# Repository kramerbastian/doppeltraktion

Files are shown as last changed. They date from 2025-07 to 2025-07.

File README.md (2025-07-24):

# *doppeltraktion*

Doppeltraktion (German for double heading — that's when two locomotives pull together on a train) is the world's most intuitive model railway throttle. It has ≈6x fewer buttons and switches than market competitors, such as the Uhlenbrock Intellibox II. It connects to your model railroad using LCC or to your computer via USB to control software such as RocRail or JMRI*¹ and can control two locomotives simultaneously. <br>
<sub>*¹ not yet implemented</sub>

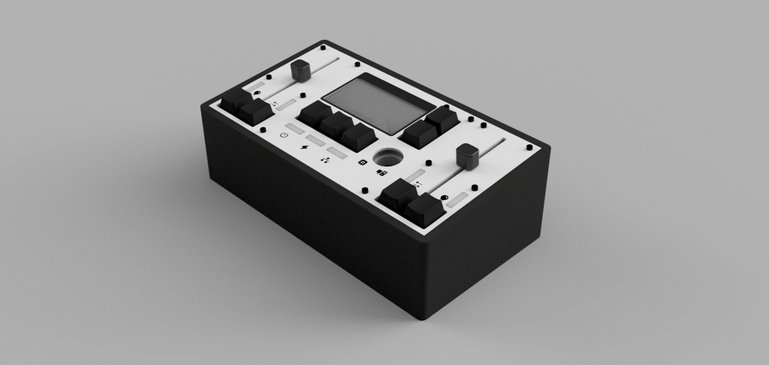
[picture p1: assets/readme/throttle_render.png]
Rendered model


### Functions

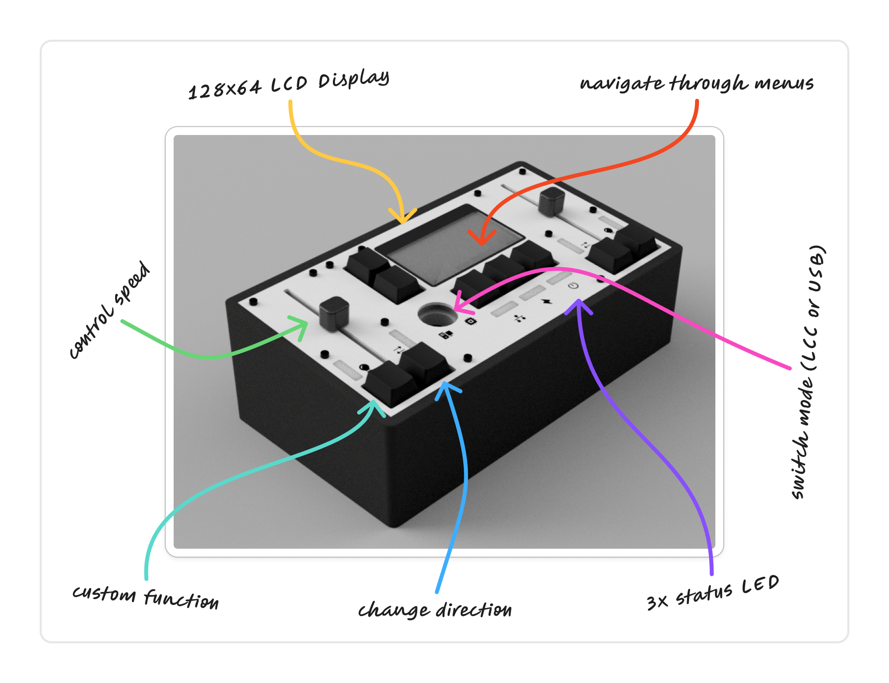
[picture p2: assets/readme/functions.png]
Functions of the throttle


### What is LCC?

LCC is a relatively new standard by the NMRA to control devices using a CAN bus. It's completely free and open-source, unlike alternatives like LocoNet, which comes with a pretty hefty licensing fee for device manufacturers.

### Motivation

I've been building on my model railway from an early age. As time progressed, the electronics and operations became so complicated that nobody else could really control it. That's why I always wanted to build a physical throttle that's not dependent on external computers or phones. Everything should be ready to use when you turn on the power. Of course, there are alternatives from big manufacturers, such as the mentioned Intellibox or the ESU ECoS, but these devices are very expensive (500€+) and aren't compatible with my DIY DCCEX base station.

### Design

It might seem a bit unusual to have five PCBs for this relatively small project, but to keep PCB costs low (by being under 100x100mm), I decided to split the covers (aluminum PCBs) and those boards where the switches, LEDs, and potentiometers mount. The PCBs on the side are identical. Everything is connected to a custom, small control board, which houses the ESP32 as well as all the CAN circuitry (for LCC).
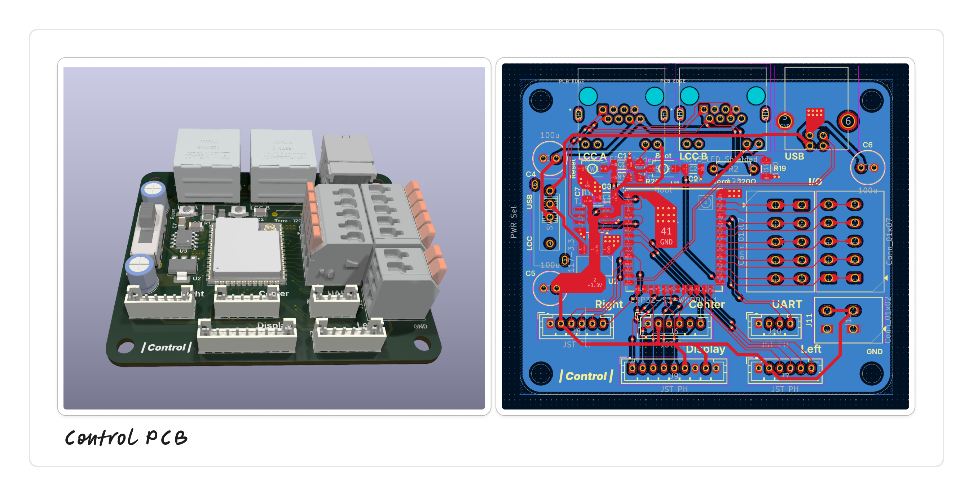
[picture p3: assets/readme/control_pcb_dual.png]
control PCB

By also splitting the base into two parts, everything should fit on the 180x180mm build plate of the A1 mini.

The plates (that‘s where the switches mount mechanically) use a sandwich design (top plate - bottom plate - PCB) to avoid having to use supports and ensure dimensional accuracy for mounting the switches.

I couldn’t find a good CAD model or accurate dimensions for the 16mm selector knob, so there’s a hole in the cover and the plates beneath it. The cutout size should be correct. I just need to verify the depth and maybe adjust the top side plate once the switch arrives.

#### Designed Parts

| Name | Image | File | Quantity  |
|---|---|---|---|
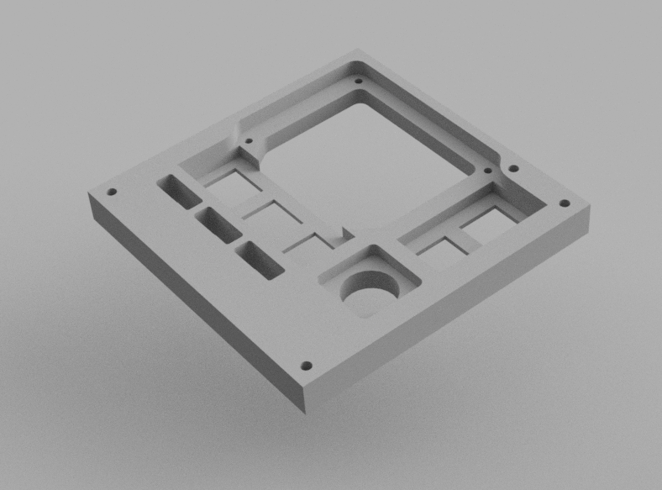
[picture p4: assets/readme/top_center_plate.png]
top center plate
| Top center plate |  | [STL](./production/3d/top_center_plate.stl) | 1 |
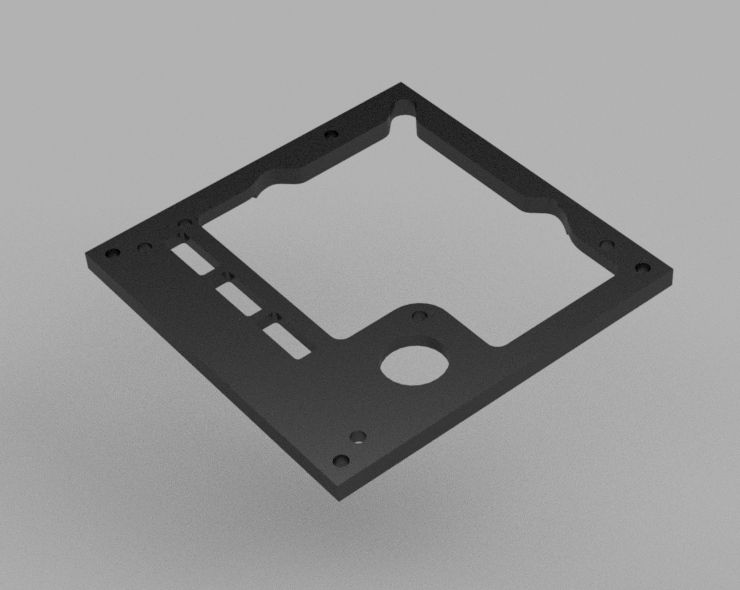
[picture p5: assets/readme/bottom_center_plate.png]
bottom center plate
| Bottom center plate |  | [STL](./production/3d/bottom_center_plate.stl) | 1 |
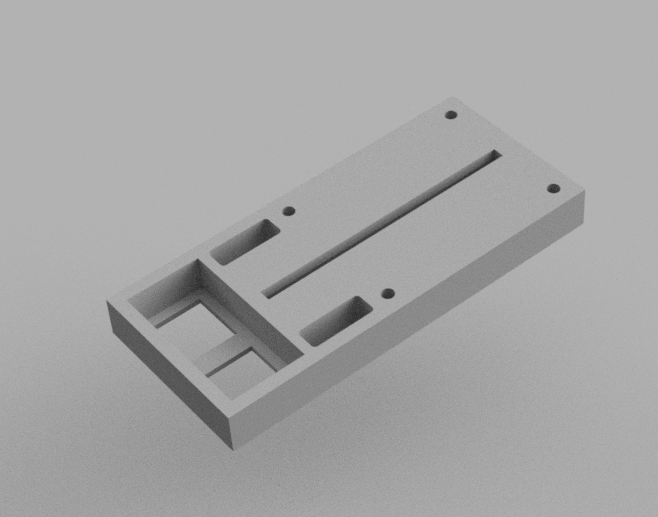
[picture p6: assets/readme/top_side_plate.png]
top side plate
| Top side plate |  | [STL](./production/3d/top_side_plate.stl) | 2 |
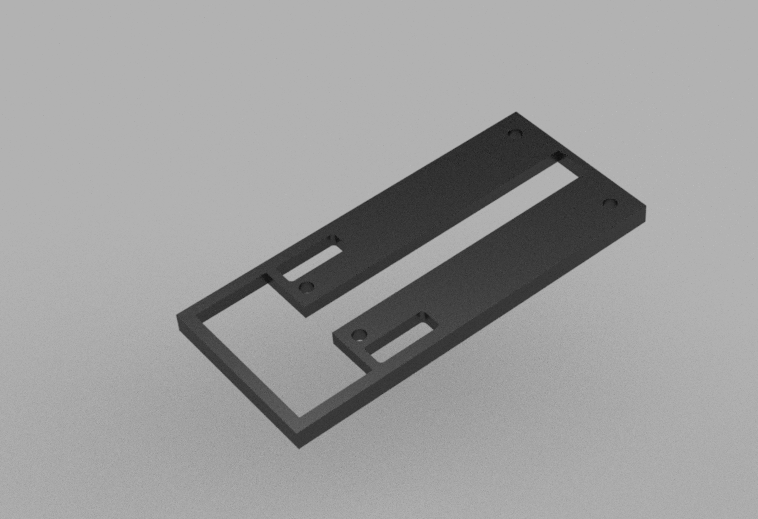
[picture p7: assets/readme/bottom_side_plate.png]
bottom side plate
| Bottom side plate |  | [STL](./production/3d/bottom_side_plate.stl) | 2 |
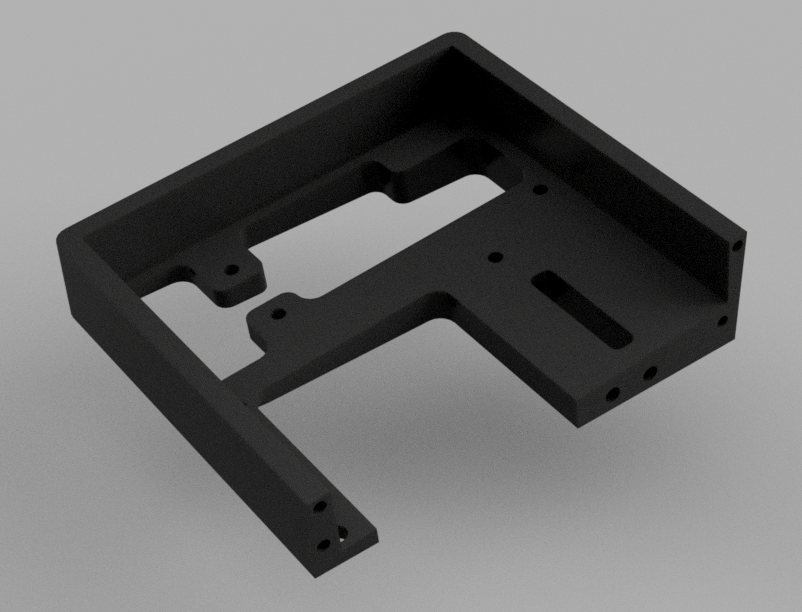
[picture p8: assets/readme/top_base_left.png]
top left base
| Top left base |  | [STL](./production/3d/top_base_left.stl.stl) | 1 |
| Top right base | bottom left base | [STL](./production/3d/top_base_right.stl) | 1 |
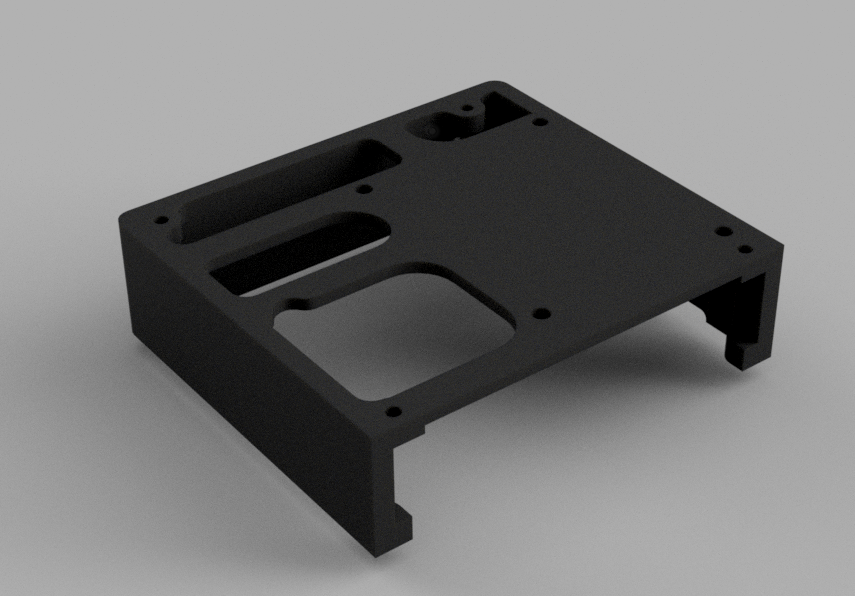
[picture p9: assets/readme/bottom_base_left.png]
bottom left base
| Bottom left base |  | [STL](./production/3d/bottom_base_left.stl.stl) | 1 |
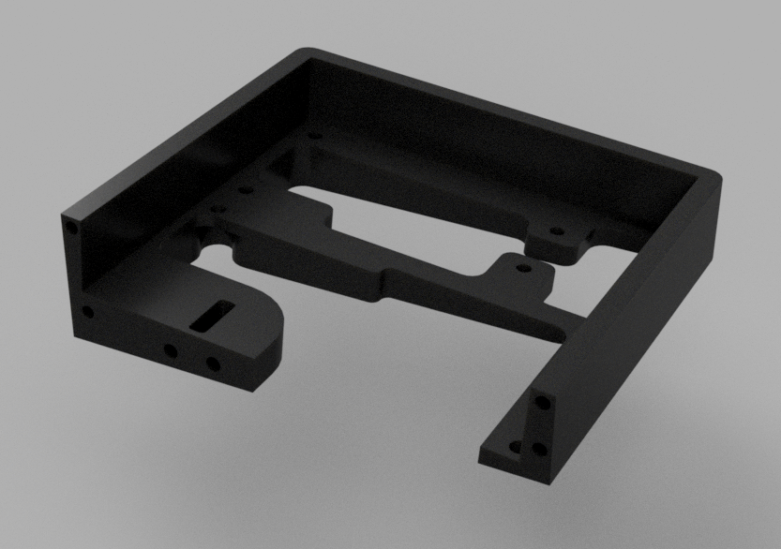
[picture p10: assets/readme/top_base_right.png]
bottom right base
| Bottom right base |  | [STL](./production/3d/bottom_base_right.stl) | 1 |
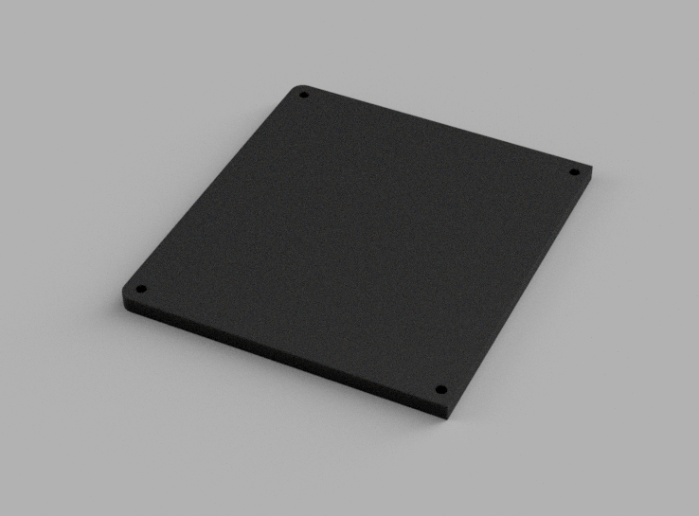
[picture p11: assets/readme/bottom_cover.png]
bottom left cover
| Bottom cover |  | [STL](./production/3d/bottom_cover.stl) | 2 |
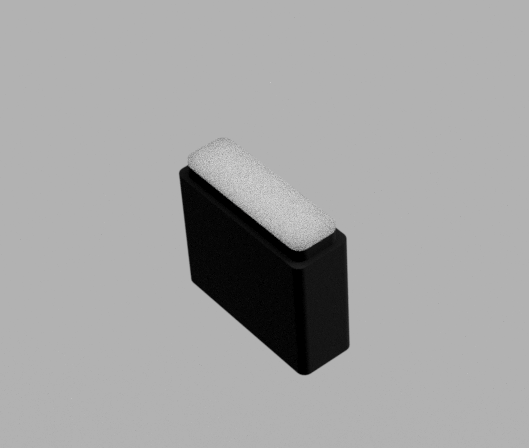
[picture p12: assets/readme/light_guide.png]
| Light guide <br> (print the last layer in white PLA)  |  | [STL](./production/3d/light_guide.stl) | 7 |
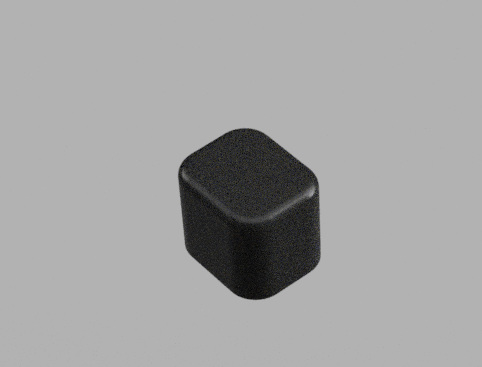
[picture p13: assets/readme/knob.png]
| Knob |  | [STL](./production/3d/knob.stl) | 1 |
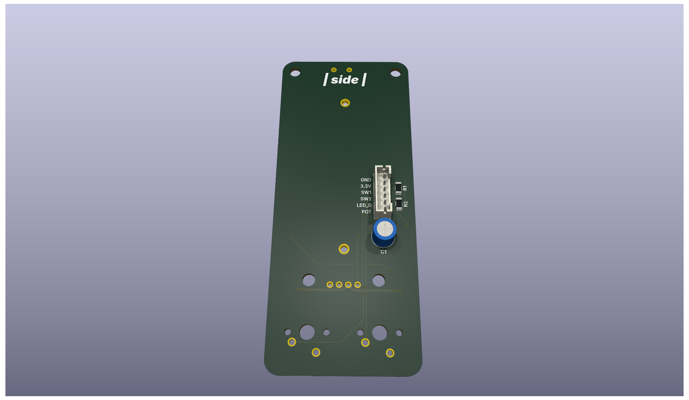
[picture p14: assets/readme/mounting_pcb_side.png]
| Mounting PCB side |  | [Gerber](./production/pcbs/side.zip) | 2 |
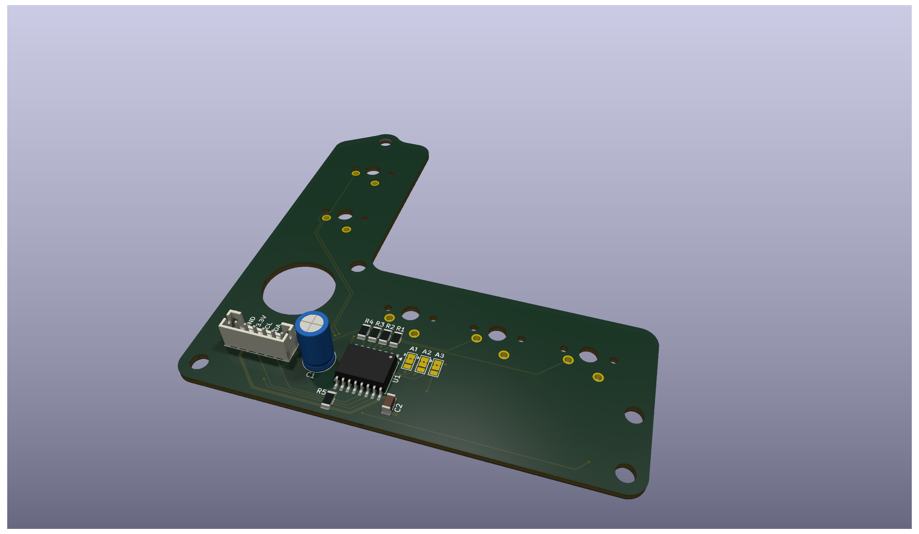
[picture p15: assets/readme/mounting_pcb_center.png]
| Mounting PCB center |  | [Gerber](./production/pcbs/center.zip) | 1 |
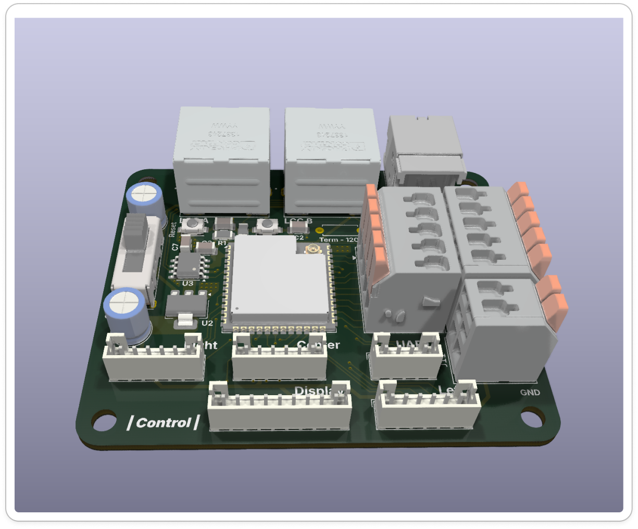
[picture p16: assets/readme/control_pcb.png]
| Control PCB |  | [Gerber](./production/pcbs/control.zip) | 1 |
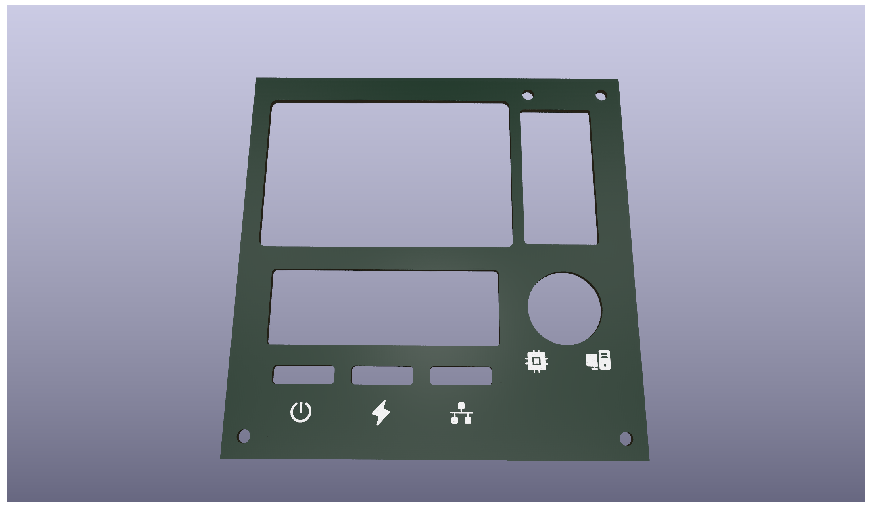
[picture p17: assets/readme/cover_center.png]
| Center cover |  | [Gerber](./production/pcbs/cover_center.zip) | 1 |
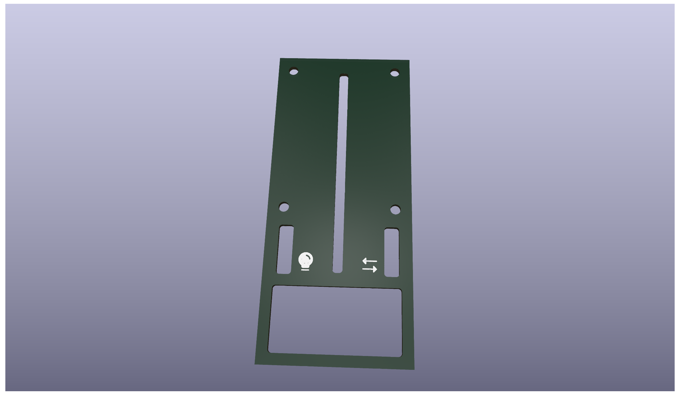
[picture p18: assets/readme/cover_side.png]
| Side cover |  | [Gerber](./production/pcbs/cover_side.zip) | 2 |

### Assembly

1. Print all necessary parts: 2x [top side plate](./production/3d/top_side_plate.stl), 2x [bottom side plate](./production/3d/bottom_side_plate.stl), 1x [top center plate](./production/3d/top_center_plate.stl), 1x [bottom center plate](./production/3d/bottom_center_plate.stl), 1x [top left base](./production/3d/top_base_left.stl), 1x [top right base](./production/3d/top_base_right.stl), 1x [bottom left base](./production/3d/bottom_base_left.stl), 1x [bottom right base](./production/3d/bottom_base_right.stl), 1x [bottom left cover](./production/3d/bottom_cover_left.stl), 1x [bottom right cover](./production/3d/bottom_cover_right.stl). (I know these names are awful, but I couldn‘t come up with better ones.)

2. Insert the heat-set inserts into their respective holes.

3. Mount all the PCBs and solder the switches in place.

4. You can now secure the plates onto the top base. With the control board mounted on the bottom base, it can also be secured to the top base.

5. Now is the time to run the wires from the modules (2x side, 1x center) and the display to the control board. Also, wire up the selector knob to the WAGO terminals and ground.

6. The final step is to screw both the top cover (the aluminium one) and the bottom cover onto the construction.

### BOM

|Part |Manufacturer |Product |Quantity|Price each|Total Price|Link |
|---|---|---|---|---|---|---|
|Inserts |YMAX |Brass Threaded Insert Nut Kit |1 | $1.460 | $1.46 | [Link](https://www.aliexpress.com/item/1005006472962973.html) |
|Display |EstarDyn |12864-06D |1 | $6.250 | $6.25 |[Link](https://www.aliexpress.com/item/1005006160620381.html) |
|Rotary Knob |Sweideer |LA-155C |1 | $2.630 | $2.63 |[Link](https://www.aliexpress.com/item/1005007495183351.html) |
|Switches |- |10 Pieces Keyboard Replacement Parts|1 | $1.590 | $1.59 |[Link](https://www.aliexpress.com/item/1005004341695529.html) |
|Keycaps |- |B0KA 20PCs PBT Blank |1 | $4.470 | $4.47 |[Link](https://www.aliexpress.com/item/1005004525231272.html) |
|M2x5 12x |SCREWHOME |50pcs M2x5mm ULTRATHIN |1 | $1.460 | $1.46 |[Link](https://www.aliexpress.com/item/1005005070119421.html) |
|M2x10 4x |LIYA |50pcs M2x10mm |1 | $1.560 | $1.56 |[Link](https://www.aliexpress.com/item/32810872544.html) |
|M3x20 2x |LIYA |50pcs M3x20mm |1 | $2.760 | $2.76 |[Link](https://www.aliexpress.com/item/32810872544.html) |
|M3x8 8x |LIYA |50pcs M3x8mm |1 | $1.730 | $1.73 |[Link](https://www.aliexpress.com/item/32810872544.html) |
|M3x8 Countersunk 8x |ZONST |50pcs M3x8mm Countersunk |1 | $1.810 | $1.81 |[Link](https://www.aliexpress.com/item/1005002333132596.html) |
|M3x12 12x |LIYA |50pcs M3x12mm |1 | $2.060 | $2.06 |[Link](https://www.aliexpress.com/item/32810872544.html) |
|M3x10 5x |LIYA |50pcs M3x10mm |1 | $1.940 | $1.94 |[Link](https://www.aliexpress.com/item/32810872544.html) |
|ESP32-S3 |EXPRESSIF |ESP32-S3-WROOM-1U-N16R2 |1 | $5.660 | $5.66 |[Link](https://lcsc.com/product-detail/WiFi-Modules_ESPRESSIF-ESP32-S3-WROOM-1U-N16R8_C3013946.html) |
|LDO |Advanced Monolithic Systems|AMS1117-3.3 |5 | $0.170 | $0.85 |[Link](https://lcsc.com/product-detail/Voltage-Regulators-Linear-Low-Drop-Out-LDO-Regulators_Advanced-Monolithic-Systems-AMS1117-3-3_C6186.html)|
|CAN transceiver |NXP |TJA1051T,118 |1 | $0.960 | $0.96 |[Link](https://lcsc.com/product-detail/CAN-Transceivers_NXP-TJA1051T-118_C18387.html) |
|I/O expander |HGSEMI |PCF8574T/TR |1 | $0.790 | $0.79 |[Link](https://lcsc.com/product-detail/I-O-Expanders_HGSEMI-PCF8574T-TR_C2987288.html) |
|4 pin connector |JST |B4B-PH-K-S(LF)(SN) |10 | $0.041 | $0.41 |[Link](https://lcsc.com/product-detail/Wire-To-Board-Connector_JST-B4B-PH-K-S-LF-SN_C131334.html) |
|6 pin connector |JST |B6B-PH-K-S(LF)(SN) |10 | $0.067 | $0.67 |[Link](https://lcsc.com/product-detail/Wire-To-Board-Connector_JST-B6B-PH-K-S-LF-SN_C131342.html) |
|9 pin connector |JST |B9B-PH-K-S(LF)(SN) |5 | $0.051 | $0.26 |[Link](https://lcsc.com/product-detail/Wire-To-Board-Connector_JST-B9B-PH-K-S-LF-SN_C157968.html) |
|4 pin connector housing  |JST |PHR-4 |50 | $0.016 | $0.79 |[Link](https://lcsc.com/product-detail/Housings-Wire-To-Board-Wire-To-Wire_JST-PHR-4_C111514.html) |
|6 pin connector housing  |JST |PHR-6 |20 | $0.020 | $0.40 |[Link](https://lcsc.com/product-detail/Housings-Wire-To-Board-Wire-To-Wire_JST-PHR-6_C157952.html) |
|9 pin connector housing  |JST |PHR-9 |20 | $0.036 | $0.72 |[Link](https://lcsc.com/product-detail/Housings-Wire-To-Board-Wire-To-Wire_JST-PHR-9_C157949.html) |
|Connector contact |JST |SPH-002T-P0.5S |100 | $0.008 | $0.80 |[Link](https://lcsc.com/product-detail/Housing-Contact_JST-SPH-002T-P0-5S_C111515.html) |
|USB-B port |TE Connectivity |292304-1 |1 | $0.470 | $0.47 |[Link](https://lcsc.com/product-detail/USB-Connectors_TE-Connectivity-292304-1_C86462.html) |
|100uF capacitors |Rubycon |35ZLH100MEFC6.3X11 |10 | $0.059 | $0.59 |[Link](https://lcsc.com/product-detail/Aluminum-Electrolytic-Capacitors-Leaded_Rubycon-35ZLH100MEFC6-3X11_C109392.html) |
|100nF capacitors |Samsung Electro-Mechanics  |CL31B104KBCNNNC |20 | $0.137 | $2.74 |[Link](https://lcsc.com/product-detail/Multilayer-Ceramic-Capacitors-MLCC-SMD-SMT_Samsung-Electro-Mechanics-CL31B104KBCNNNC_C24497.html) |
|10kOhm resistors |YAGEO |RC1206FR-0710KL |100 | $0.004 | $0.37 |[Link](https://lcsc.com/product-detail/Chip-Resistor-Surface-Mount_YAGEO-RC1206FR-0710KL_C132649.html) |
|Sliding potentiometers |ALPSALPINE |RS6011YA600M |2 | $1.451 | $2.90 |[Link](https://lcsc.com/product-detail/Potentiometers-Variable-Resistors_ALPSALPINE-RS6011YA600M_C470623.html) |
|RGB LEDs |XINGLIGHT |XL-5050RGBC-WS2812B |20 | $0.049 | $0.98 |[Link](https://lcsc.com/product-detail/RGB-LEDs-Built-in-IC_XINGLIGHT-XL-5050RGBC-WS2812B_C2843785.html) |
|RJ45 port - existing |Phoenix Contact |1337243 |2 | - | - |[Link](https://www.phoenixcontact.com/en-pc/products/rj45-pcb-connectors-cuc-sp-j1st-a-r4lt-thr-led-1337243) |
|WAGO terminals - existing|WAGO |2601-3105 |2 | - | - |[Link](https://www.wago.com/de/leiterplattenanschluss/leiterplattenklemme/p/2601-3105) |
|Slide switch - existing  |XKB Connection |SS13E05L2 |1 | - | - |[Link](https://lcsc.com/product-detail/Slide-Switches_XKB-Connection-SS13E05L2_C2884809.html) |
|Control PCB |JLCPCB |5x FR4 PCB |1 | $1.720 | $1.72 | |
|Side PCB |JLCPCB |5x FR4 PCB |1 | $3.440 | $3.44 | |
|Center PCB |JLCPCB |5x FR4 PCB |1 | $3.440 | $3.44 | |
|Center cover |JLCPCB |5x Aluminum PCB |1 | $3.390 | $3.39 | |
|Cover |JLCPCB |5x Aluminum PCB |1 | $3.390 | $3.39 | |
|JLCPCB shipping and taxes| | |1 | $11.020  | $11.02 | |
|LCSC shipping | | |1 | $9.420 | $9.42 | |
|**Total** | | | | | **$85.90**| |

#### Opening the CAD File
This project was built in multiple design files, which can‘t be combined without compromising the whole model. To import the CAD model, open Fusion 360, **create a new folder** and upload the [.f3z](./hardware/cad/Throttle.f3z) file into this created folder. You can now open the `Throttle` design file.

-------
<div style="display: flex; justify-items: center; flex-direction: row; gap: 4px; font-size: 12px;">
Supported by
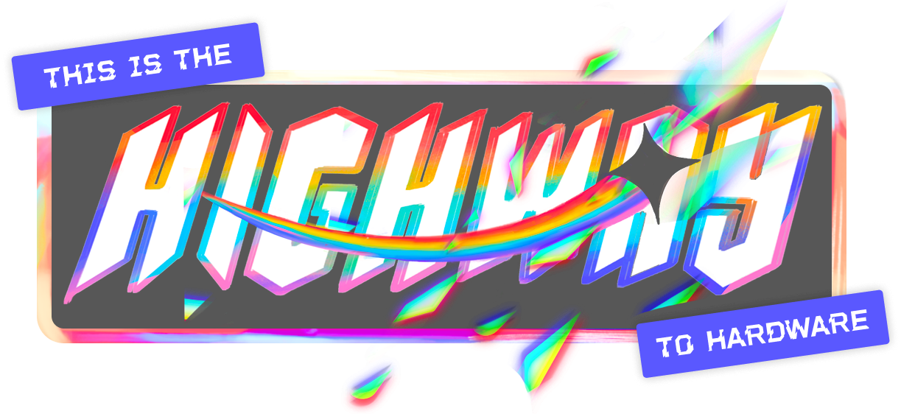
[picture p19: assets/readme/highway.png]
Highway

</div>

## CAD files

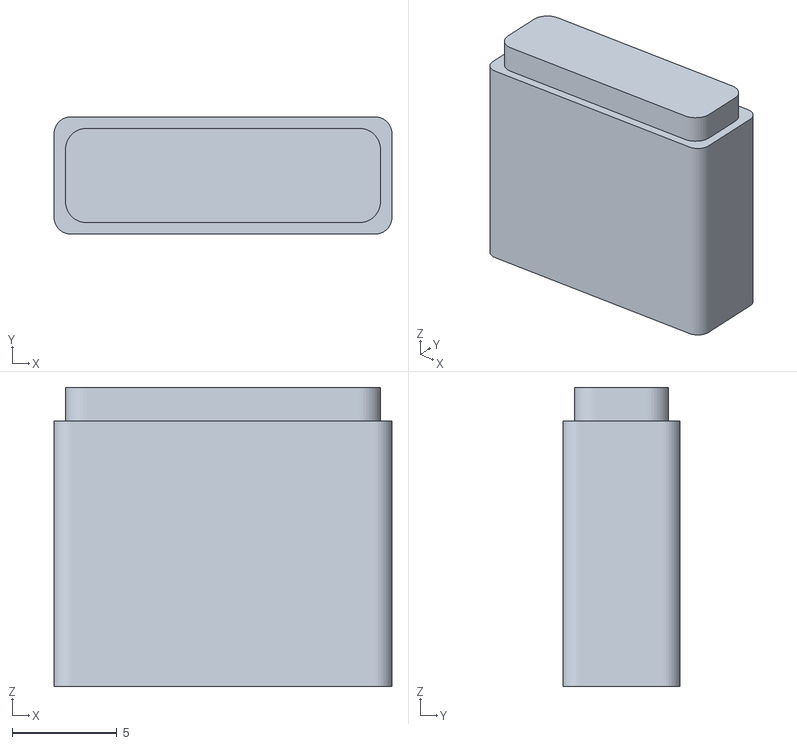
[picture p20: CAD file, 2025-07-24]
production/3d/light_guide.stl
16.1 x 5.60 x 14.3

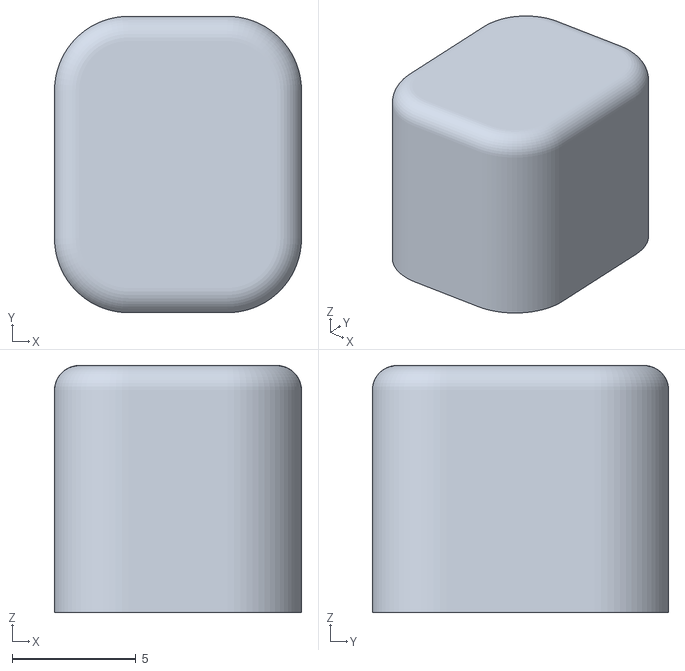
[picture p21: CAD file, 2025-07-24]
production/3d/knob.stl
10.0 x 12.0 x 10.0

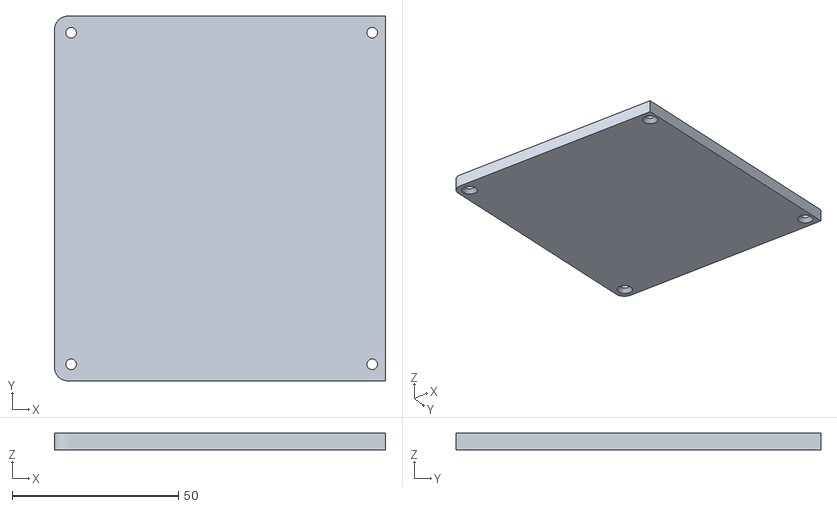
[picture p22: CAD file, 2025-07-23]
production/3d/bottom_cover.stl
99.6 x 109.7 x 5.00

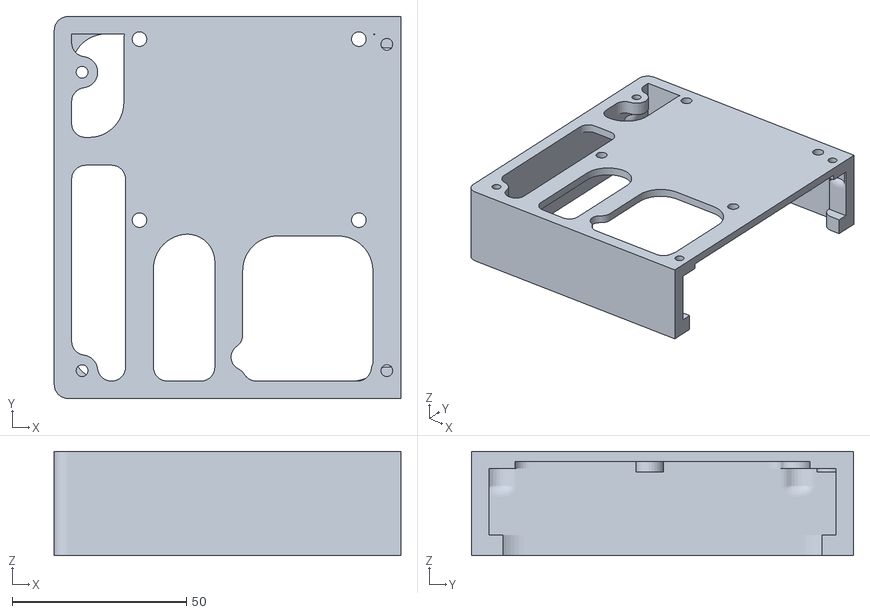
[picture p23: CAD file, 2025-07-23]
production/3d/bottom_base_left.stl
99.6 x 109.7 x 30.0

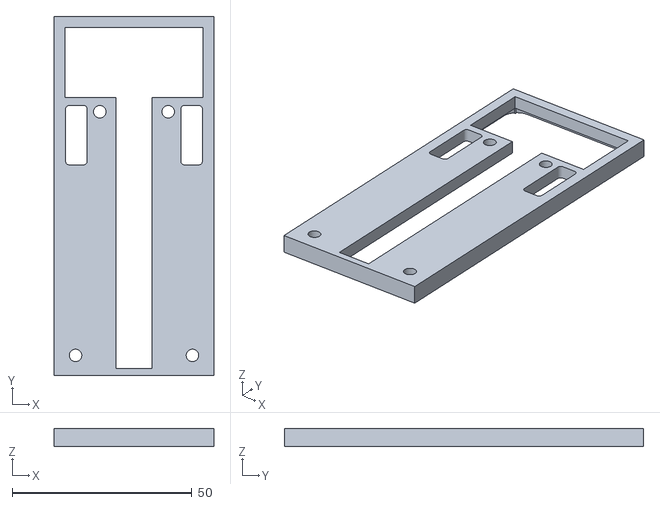
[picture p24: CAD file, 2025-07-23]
production/3d/bottom_side_plate.stl
44.6 x 100.0 x 5.15

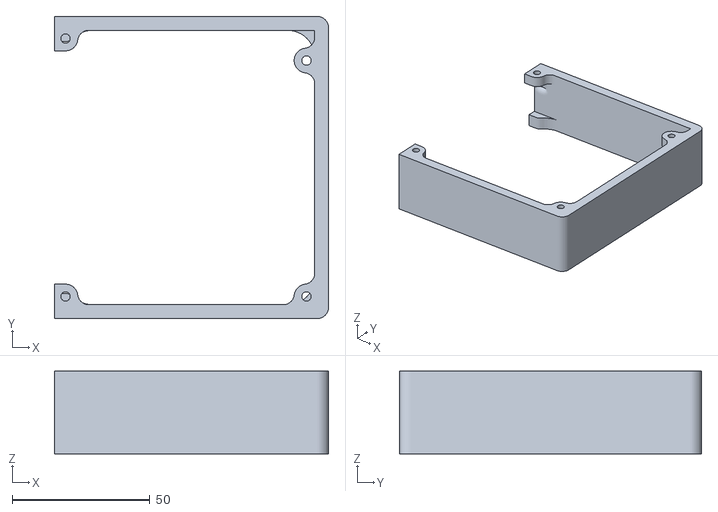
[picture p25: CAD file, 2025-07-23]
production/3d/bottom_base_right.stl
99.6 x 109.7 x 30.0

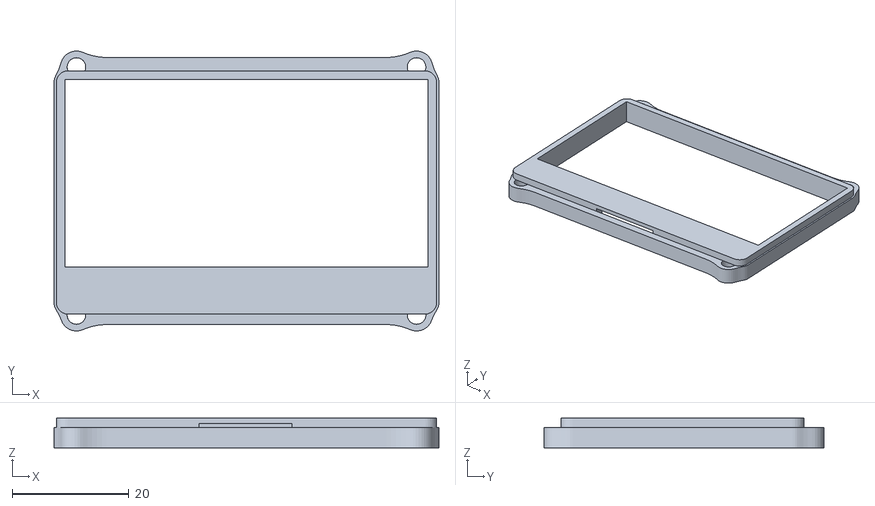
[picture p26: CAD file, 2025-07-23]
production/3d/display_module.stl
66.0 x 48.0 x 5.10

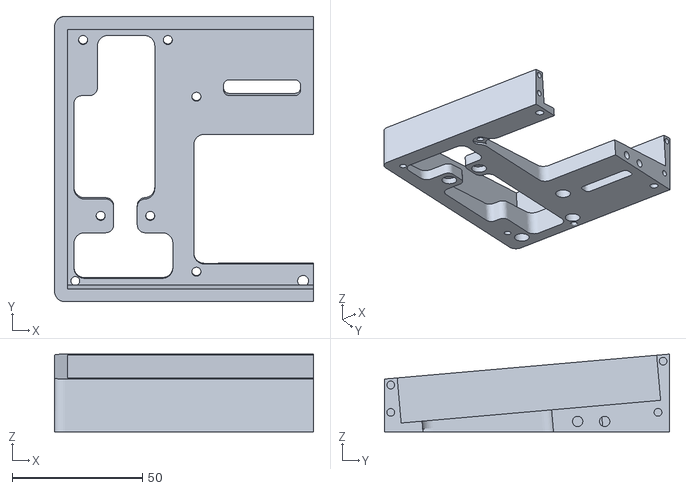
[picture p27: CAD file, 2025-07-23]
production/3d/top_base_left.stl
99.6 x 109.7 x 29.9

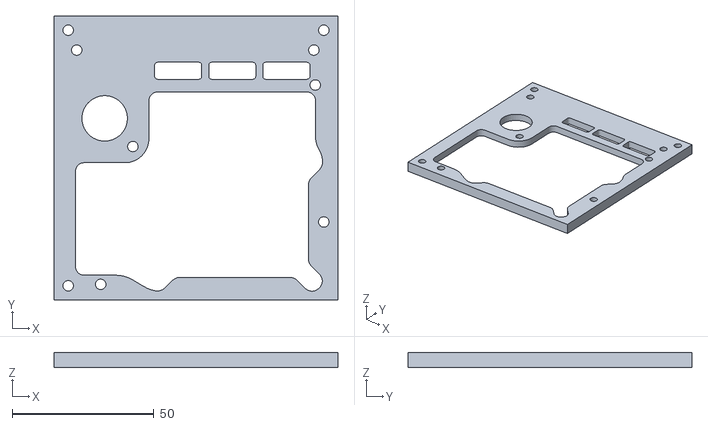
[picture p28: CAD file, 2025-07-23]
production/3d/bottom_center_plate.stl
100.0 x 100.0 x 5.15

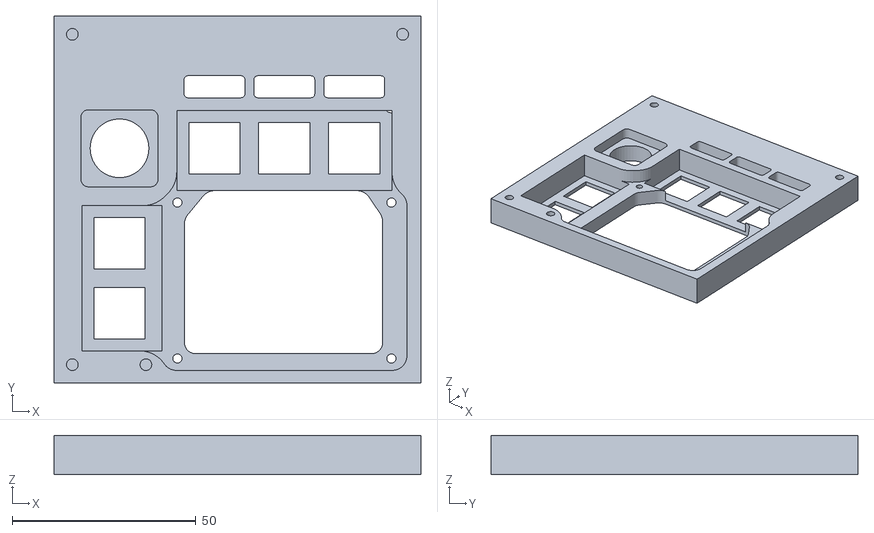
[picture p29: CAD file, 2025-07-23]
production/3d/top_center_plate.stl
100.0 x 100.0 x 10.6

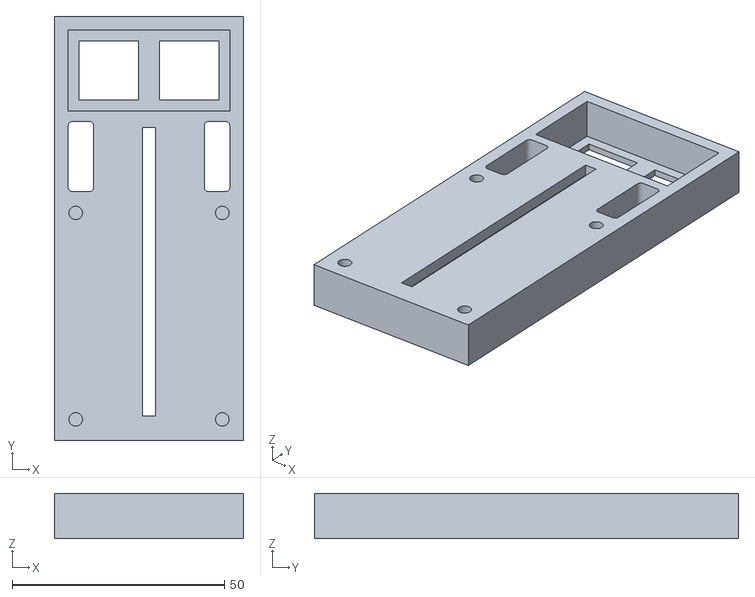
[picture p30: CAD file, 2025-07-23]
production/3d/top_side_plate.stl
44.6 x 100.0 x 10.6

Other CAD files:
production/3d/top_base_right.stl

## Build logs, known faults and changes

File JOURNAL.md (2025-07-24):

---
title: "doppeltraktion"
author: "Bastian Kramer"
description: "doppeltraktion is the world‘s most intuitive model railway throttle."
created_at: "2025-07-14"
---

<sub>Total time spent: 37.5h</sub>

### 14/07/2025
**Log 1:** After two weeks of holidays, I realized that this project would be significantly improved by using sliding potentiometers instead of rotary encoders. I would mean more complex software to check any discrepancies between the actual "real" locomotive speed and the potentiometer's position and make any previous work obsolete, but I think this extra work would definitely be worth it. You can read the journal entries of the old concept [here](./assets/journal/JOURNAL_OLD.md).

Furthermore, I think using a shared display for both throttles should bring the price on the component side down by quite a bit.

That’s why I developed this concept: a 100x100mm control board in the center (to keep JLCPCB prices low) and two identical modules on the sides. The top cover will be made from aluminum PCBs. This allows for nicely printed icons to describe each button's function and make the finished project feel a lot more polished in contrast to a simple 3D-printed cover.

To keep wiring inside the throttle minimal, a PCB with an I²C I/O expander will be positioned under each module. I'm still a bit unsure if I can fit the main electronics (MCU, RJ45 ports, etc.) on the PCB under the central module. If not, it will require another separate board stacked on top of the mentioned central module's PCB.

Because I now need aluminium panels both for the central board and the side modules (each ~$4 + shipping) as well as PCBs for the switches, etc. (each ~$2 + shipping), it will probably end up more expensive than the first idea.

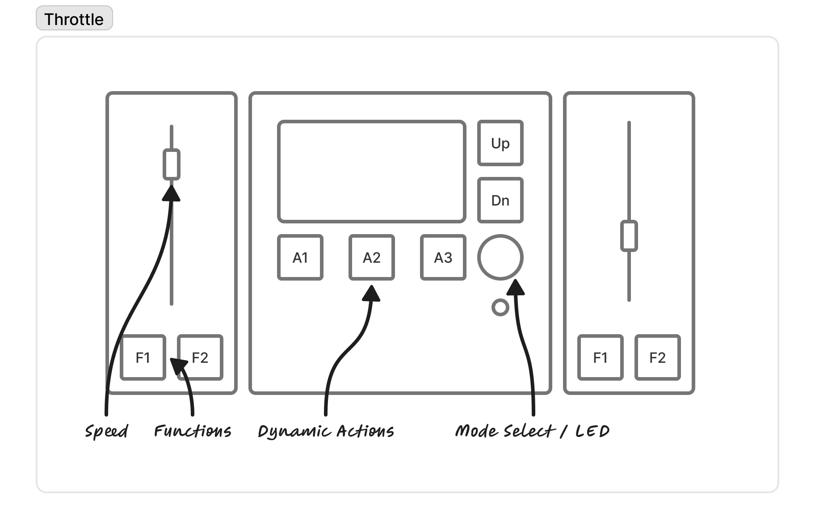
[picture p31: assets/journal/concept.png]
throttle concept

<sub>Time spent: 0.5h - Total: 0.5h</sub>

**Log 2:** With the general layout figured out, I started working on the CAD. The general methods will be similar to the previous version but still be a blank sheet design. The whole assembly will be a pretty complex sandwich: Aluminum cover – top plate (to hold the switches and display) – bottom plate (to hold the PCB) – base.
I started work on the the display module because it was the most specified part: 
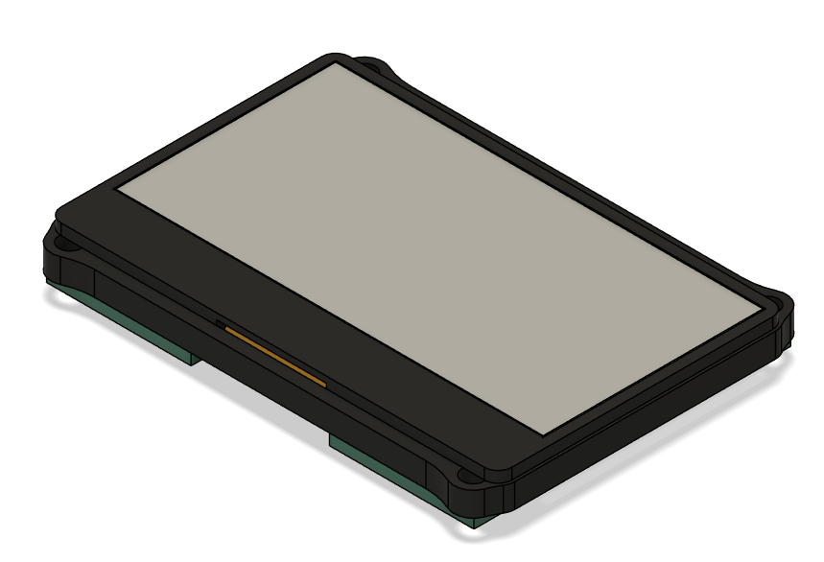
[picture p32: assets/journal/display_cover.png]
display cover

I found [this](https://de.aliexpress.com/item/1005006160620381.html) good looking LCD with a pretty small footprint for it’s ~2.5in screen size. And there’s even a [CAD model](https://grabcad.com/library/gmg12864-06d-1) for it.

<sub>Time spent: 2.5h - Total: 3h</sub>

**Log 3:** Now I could build the top plate around the display module. It's main job is to hold the key switches and a specific distance so that they don’t protrude by like 50mm over the top cover. The three holes on the bottom will display the status of stuff like track power.
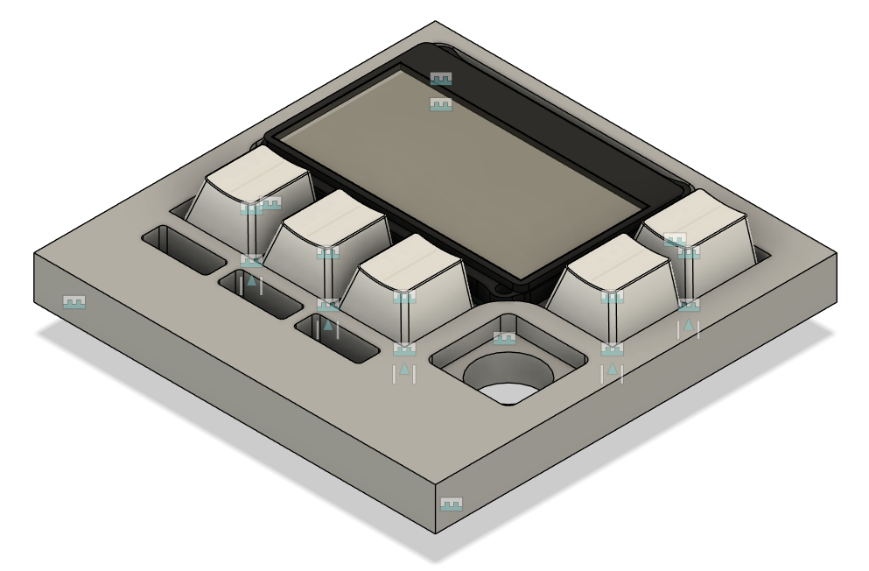
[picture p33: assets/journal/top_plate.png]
top plate


<sub>Time spent: 4h - Total: 7h</sub>

### 16/07/2025
**Log 4:** After refining the top plate a bit, I created the bottom one. It screws into the top plate using M3 screws and will house a PCB. Because the plates are split it can be easily 3D-printed.

<sub>Time spent: 2h - Total: 9h</sub>

**Log 5:** I could now export the PCB’s outline from Fusion into KiCad and start working on the PCB. It turns out it is way too small to contain all main electronics (that includes two RJ45 ports!). The board will have a PCA8574 I/O expander and connect to the main control board with an eight-pin JST-PH connector: GND – +5V – SCL – SDA – Interrupt – LED_DATA.
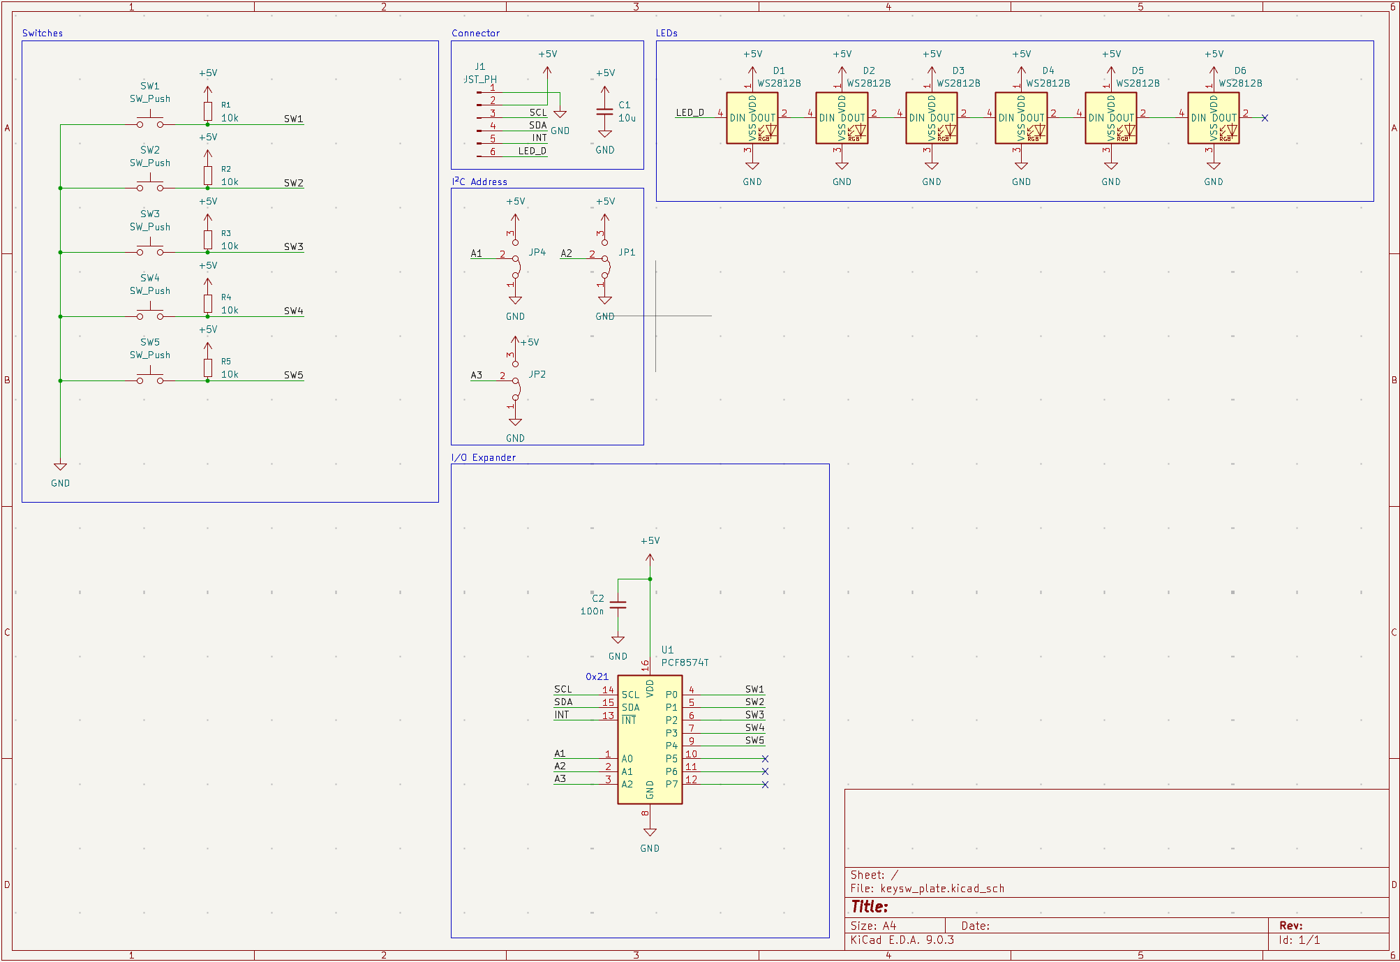
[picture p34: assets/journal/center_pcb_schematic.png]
center pcb schematic

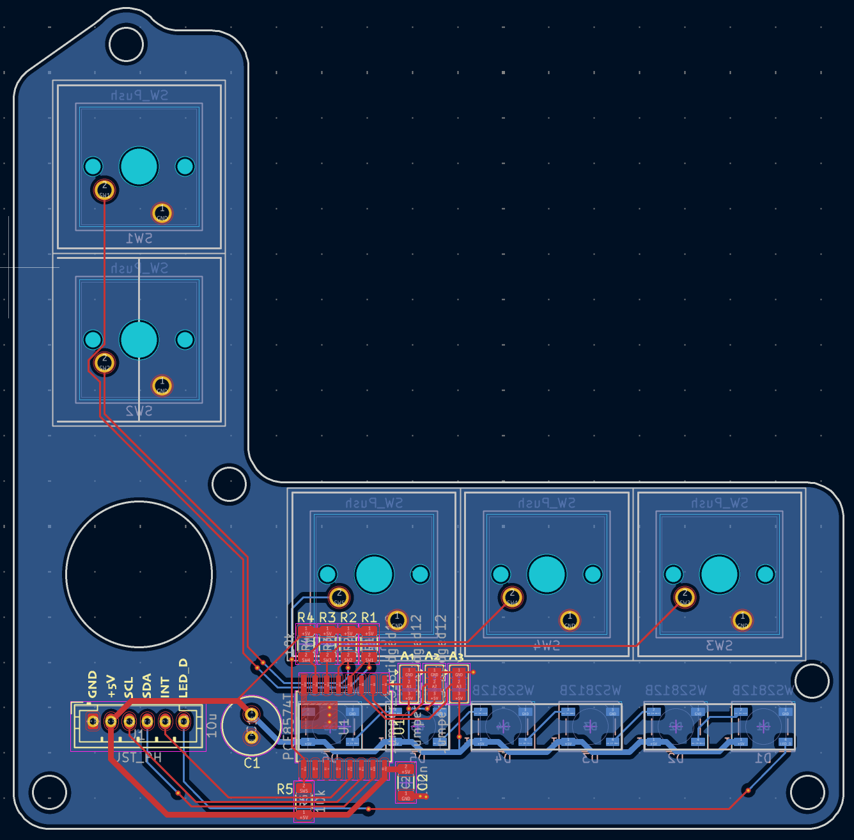
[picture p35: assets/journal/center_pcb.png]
center pcb


<sub>Time spent: 4h - Total: 13h</sub>

### 17/07/2025
**Log 6:** Today I created the first screen. It was surprisingly easy using this tool I found: [Lopaka](https://lopaka.app/editor/11258/23701). The next step is to make it interactive.
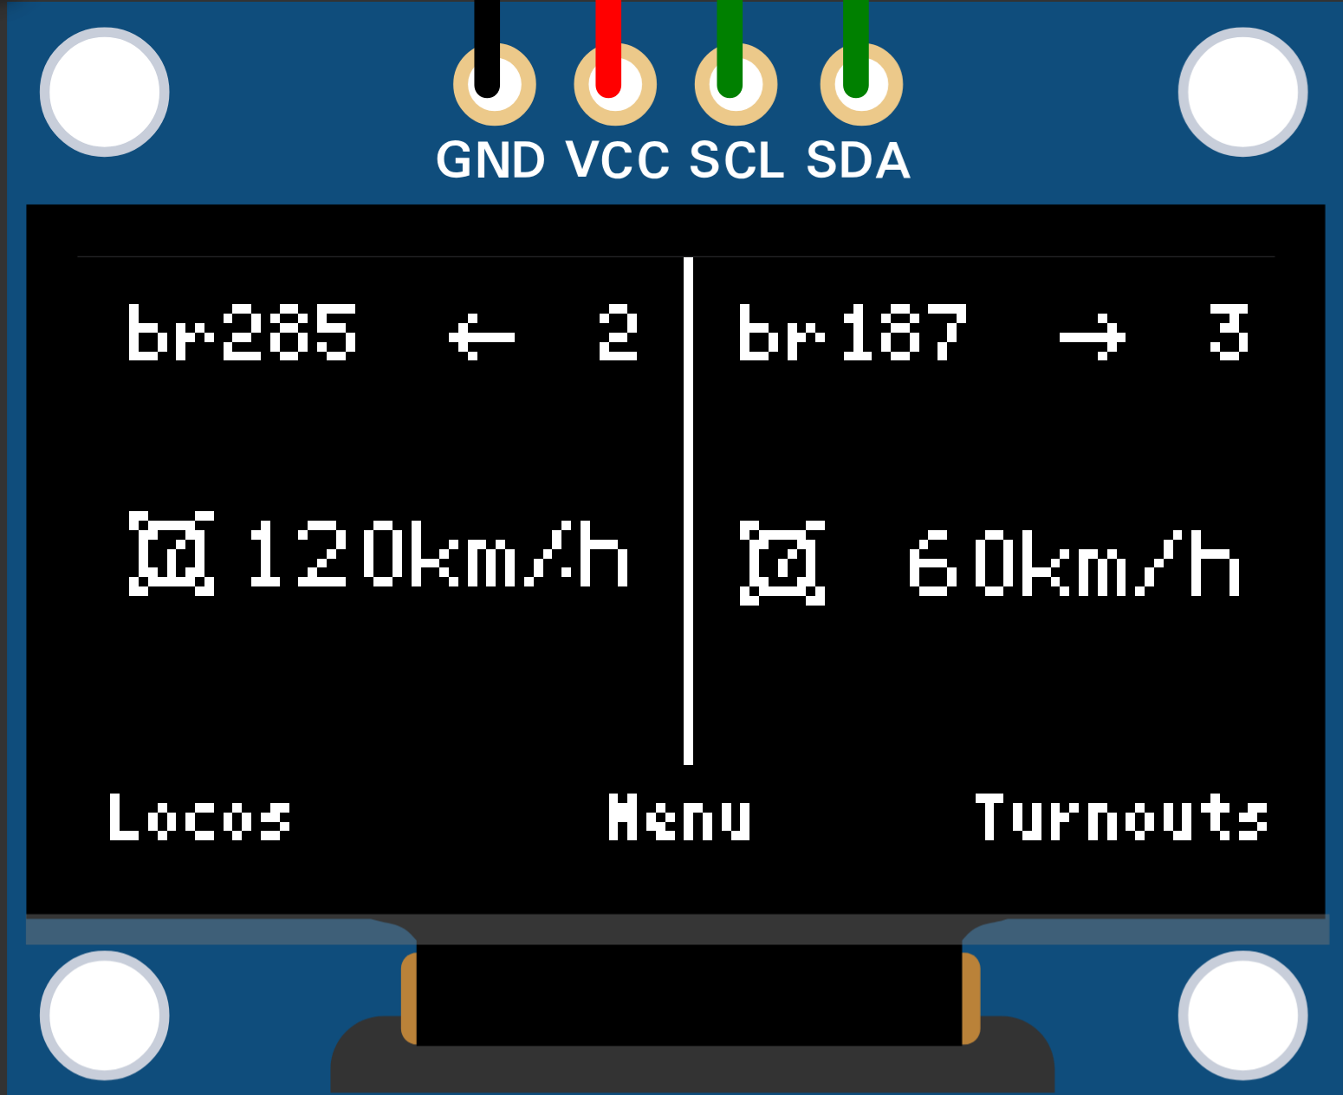
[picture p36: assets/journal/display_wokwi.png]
screen concept


<sub>Time spent: 0.5h - Total: 13.5h</sub>

**Log 7:** I copied the generated code into wokwi and made it controllable using two potentiometers. This all went well until I tried including a CAN library. The 328p doesn‘t have enough RAM the application.

<sub>Time spent: 2h - Total: 15.5</sub>

### 18/07/2025
**Log 8:** After finding out that the RAM of the ATmega 328p is by far not enough to hold both the u8g2 and CAN libraries, I chose the ESP32-S3-WROOM-1U as a new MCU. I believe it is the only easily accessible MCU that can be hand-soldered as a module. Of course I have to rework the already finished control PCB schematic.
Creating a basic schematic for such an ESP32 module is quite a bit simpler than for the 328p (no clock, etc.). It also supports programming over USB, which will make the development process a lot simpler.
I now only have to connect the GPIO pins to the ESP32. Which pins to use can be determined based on the PCB layout.
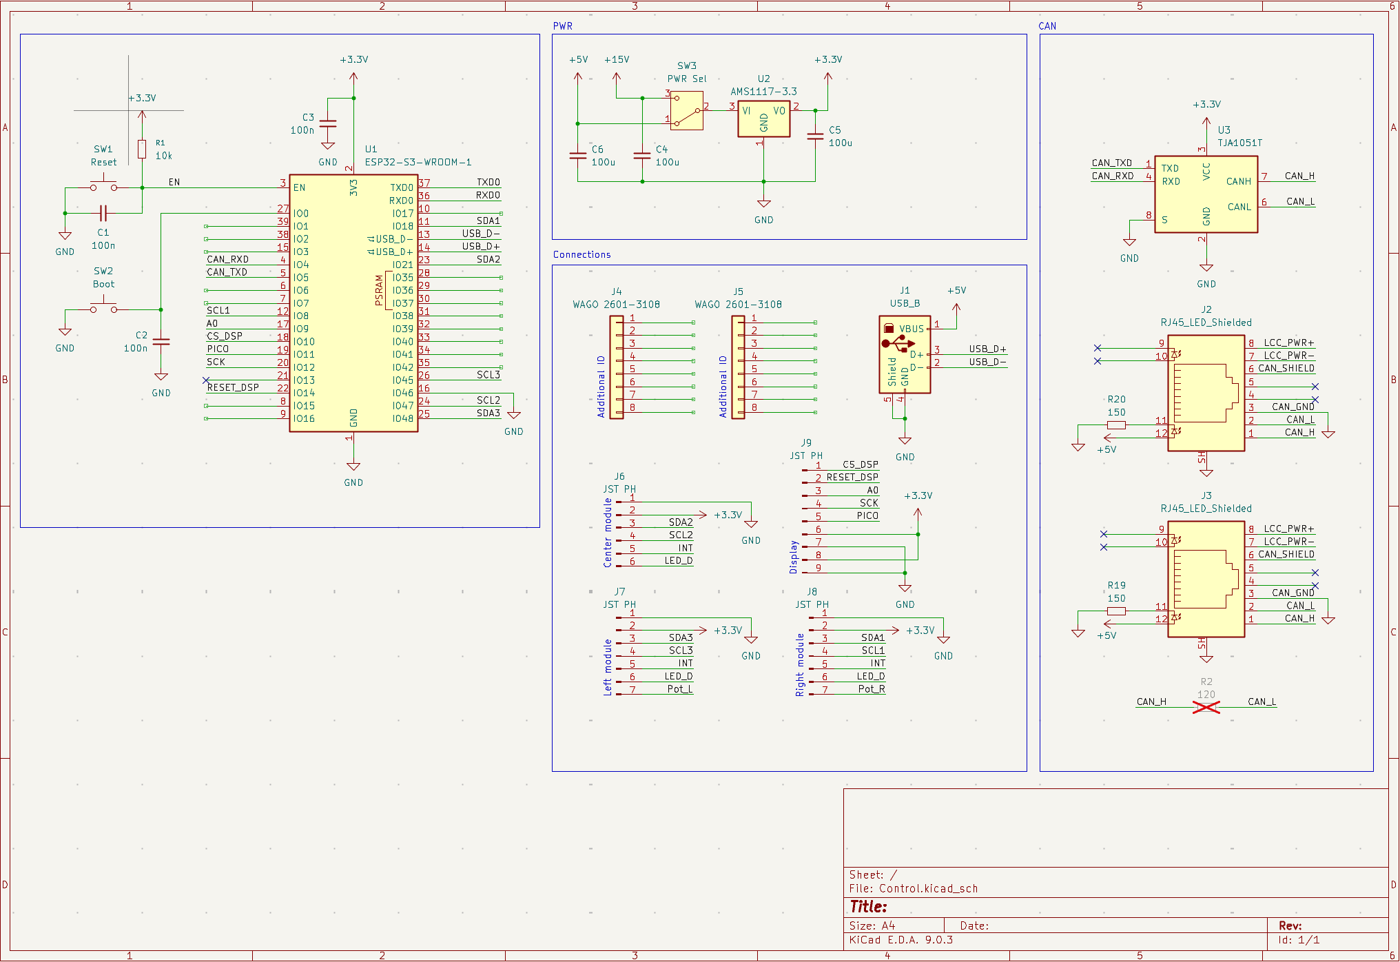
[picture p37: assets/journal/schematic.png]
control PCB schematic


<sub>Time spent: 3.5h - Total: 19h</sub>

### 19/07/2025
**Log 9:** I’m finished creating the control PCB 🎉! It was probably the most pain full PCB to layout because the space was so restricted. But in the end I managed to fit it all on two layers. All pins I didn’t use are accessible on those amazing WAGO 2601 terminals and can be used for e.g. additional switches on a control panel. In the end the left over pins where only ten, but this should be enough for at least some small layouts.
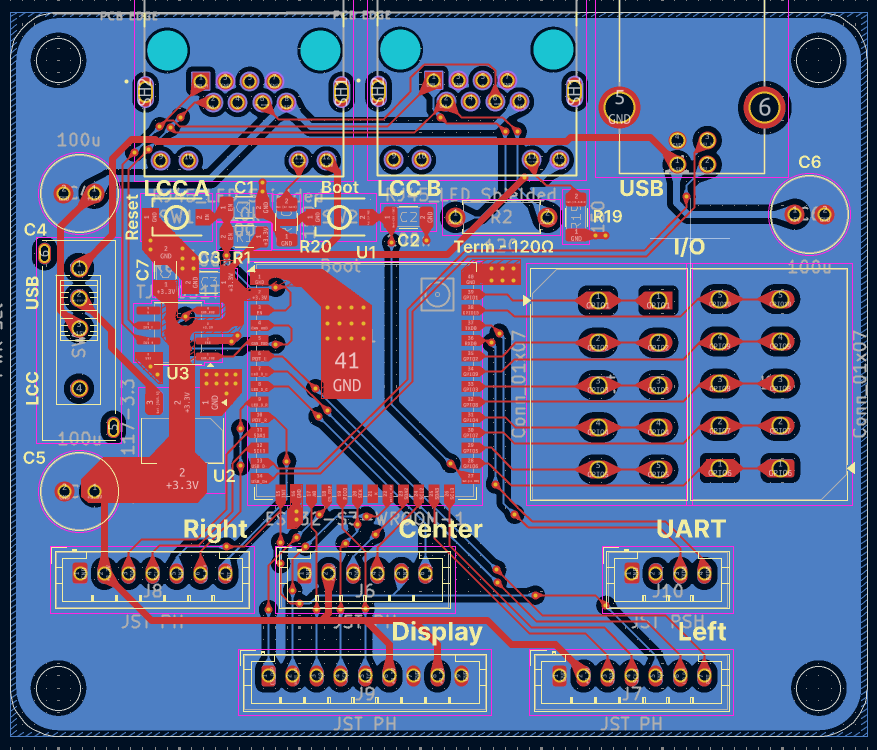
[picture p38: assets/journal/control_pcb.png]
control pcb

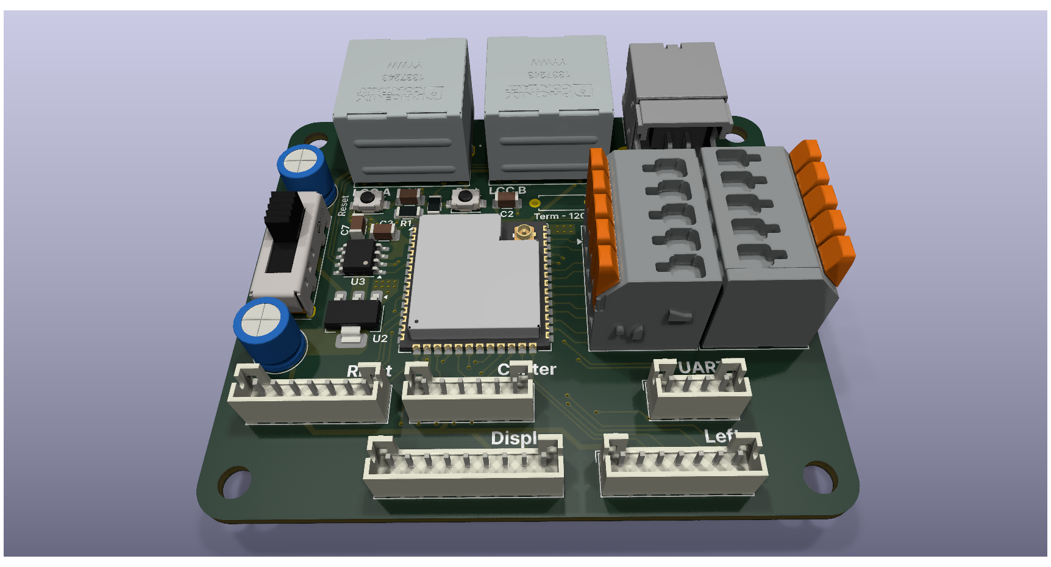
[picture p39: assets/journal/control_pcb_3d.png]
control pcb in 3d view


<sub>Time spend: 5h - Total: 24h</sub>

**Log 10:** I struggled a bit with the side panels. Both have to be exactly symmetrical to reduce part cost (for the top covers and PCBs). I wanted to put one or two switches below the sliding potentiometer (60mm of travel) but this didn’t fit on the max. 100x100mm I could use (I would have to a 45mm potentiometer but this felt a but small). In the end I decided to add two switches with corresponding lights on each side of the potentiometer.
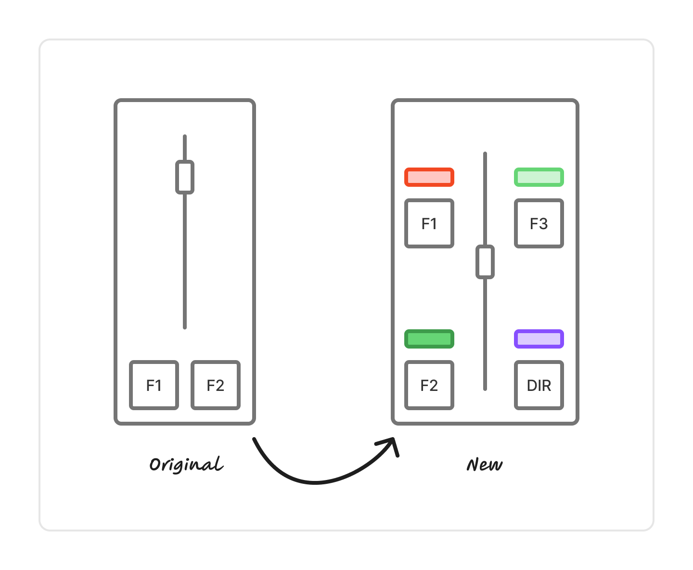
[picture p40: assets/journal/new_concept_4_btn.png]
new concept

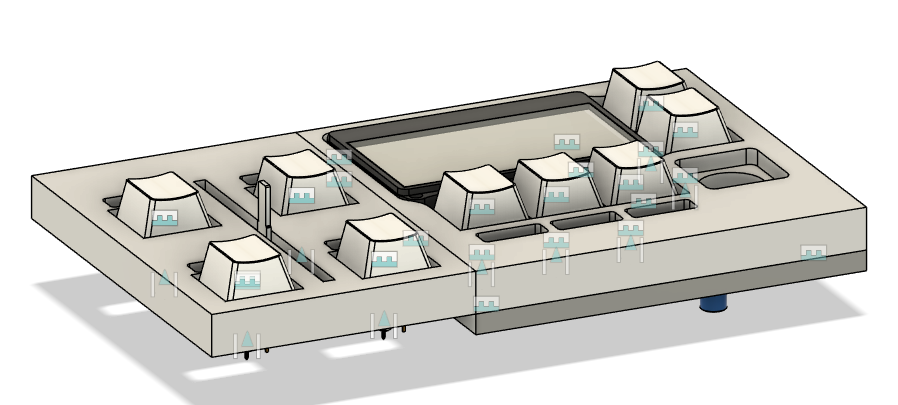
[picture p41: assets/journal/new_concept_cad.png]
new concept in CAD


<sub>Time spent: 2h - Total: 26h</sub>

### 20/07/2025
**Log 11:** Ok, never mind, I managed to fit two buttons beneath the sliding potentiometer. It looks infinitely better! It’s a similar design to the center module with its two plates that get mounted on top of each other to guarantee good tolerances for mounting the switches (as opposed to printing overhangs with supports).
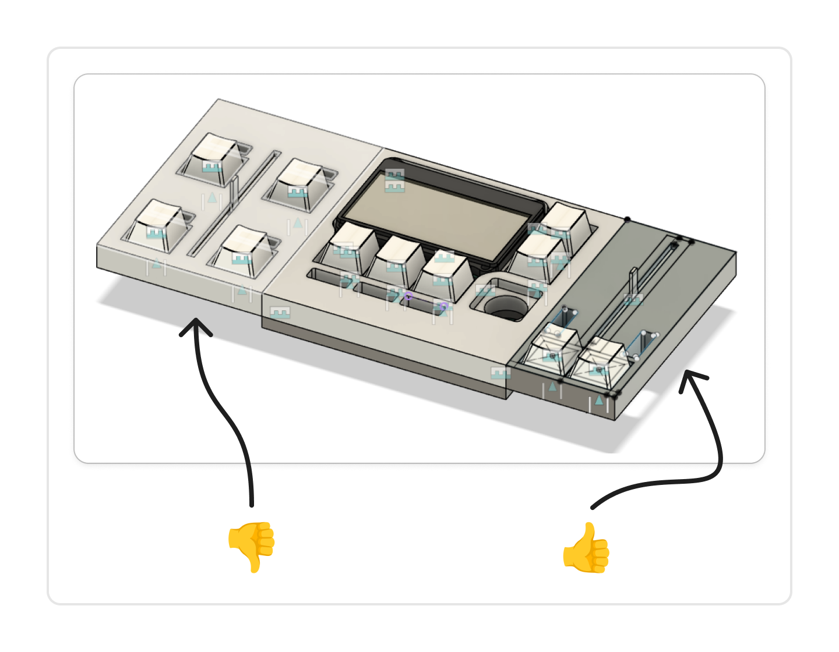
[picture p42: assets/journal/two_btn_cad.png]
old concept


<sub>Time spent: 1.5h - Total: 27.5h</sub>

**Log 12:** I also quickly put together the PCB for the side modules. It’s really simple as it contains no chip.
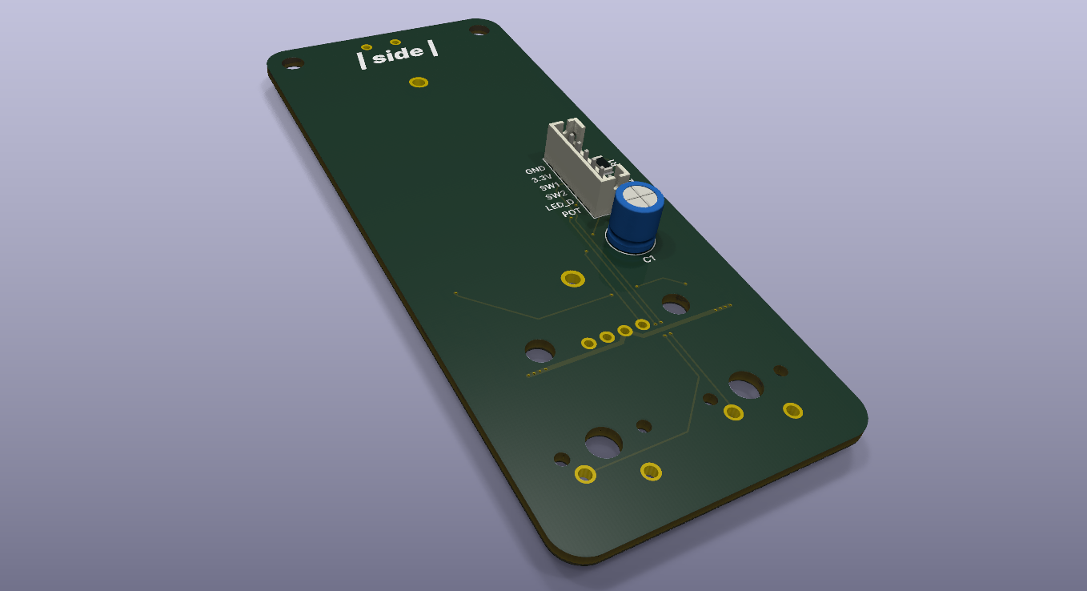
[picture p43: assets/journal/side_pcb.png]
side module PCB


<sub>Time spent: 1h - Total: 28.5h</sub>

### 21/07/2025
**Log 13:** I worked on the base today. I had to cut it in half because the entire thing would be larger than 180 × 180 mm. I also divided it vertically so that it could be printed without supports; now, it resembles the plates’ sandwich design. All is screwed together using M3 screws and inserts.
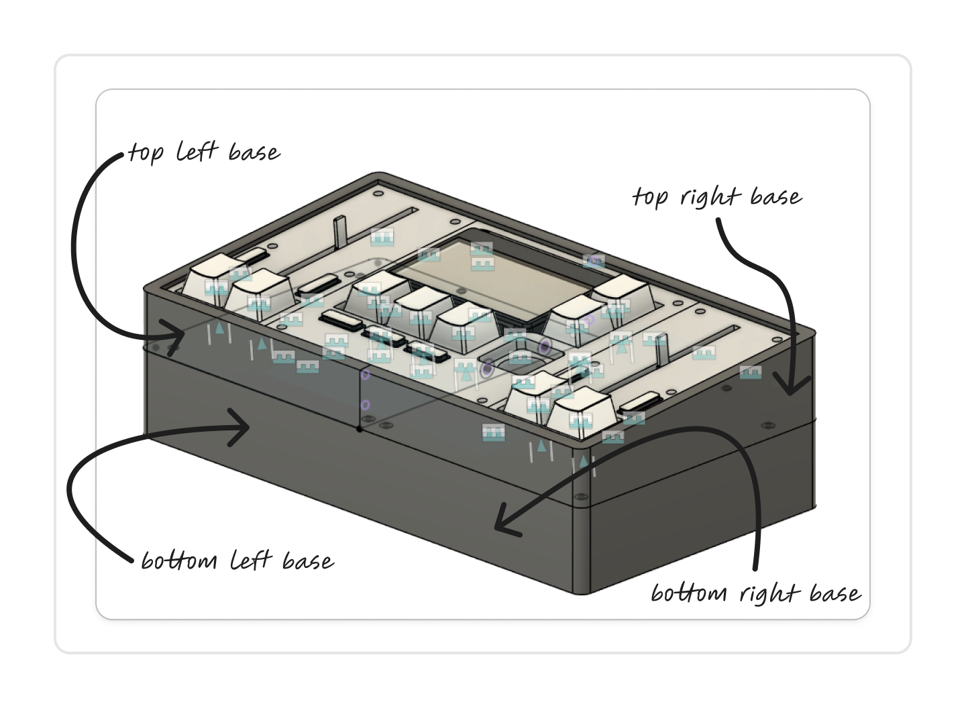
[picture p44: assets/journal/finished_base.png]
base in CAD

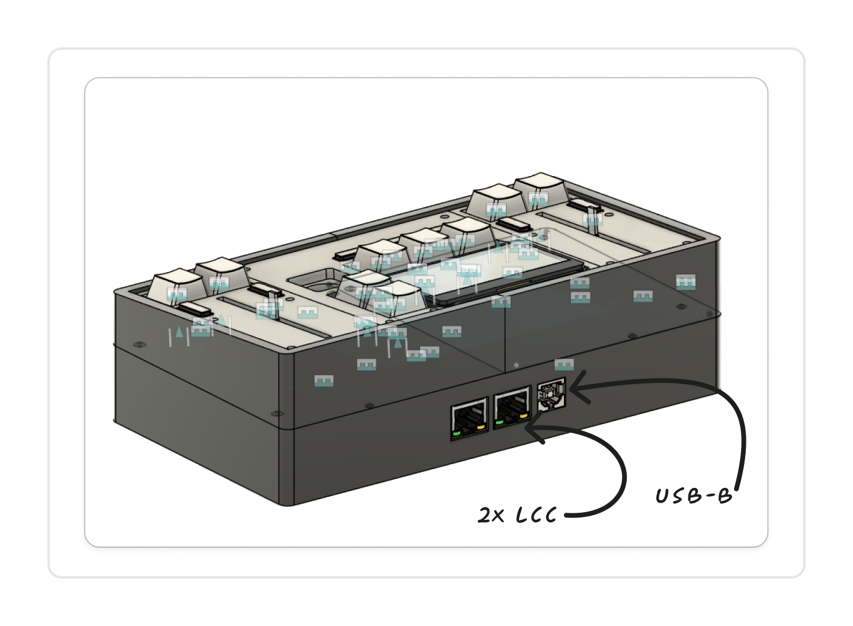
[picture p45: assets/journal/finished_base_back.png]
base in CAD from behind


I also started the first test prints. They came out pretty nice; just forgot to add holes to mount the center cover.
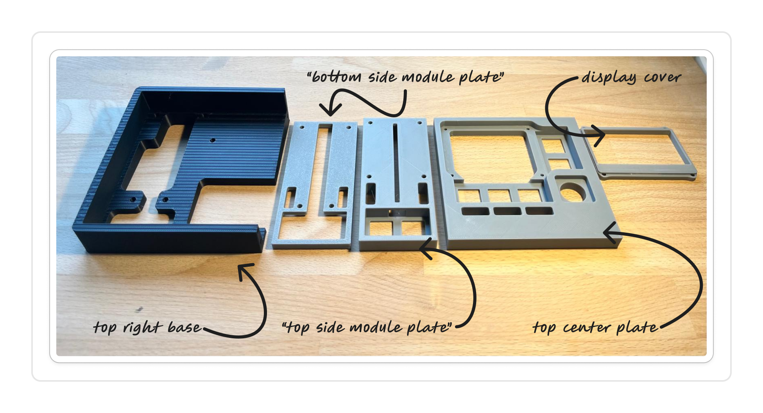
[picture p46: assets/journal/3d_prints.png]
first 3d-printed parts


<sub>Time spent: 4.5h - Total: 33h</sub>

### 23/07/2025
**Log 14:** The base still needs a bit of work. There were a few clearance problems with the top plates as well as the display. I now moved the control PCB from the center to the left so the base body can be split more easily to fit on my A1 mini. I also created a simple bottom cover. The only thing that’s still left is the top cover.
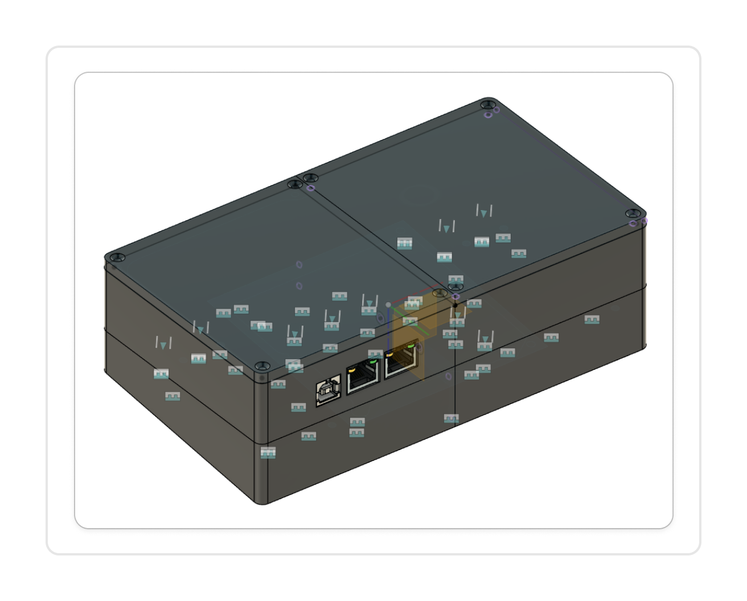
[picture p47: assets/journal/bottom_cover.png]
bottom cover


<sub>Time spent: 1.5h - Total 34.5h</sub>

**Log 15:** And I finished the top cover! I imported some nice icons from [PhosphorIcons](https://phosphoricons.com/) into KiCAD. The cover is secured with M2 bolts into the top plates. Maybe the holes can be countersunk at home to have a flush finish. I think that’s all for CAD, just documentation left…
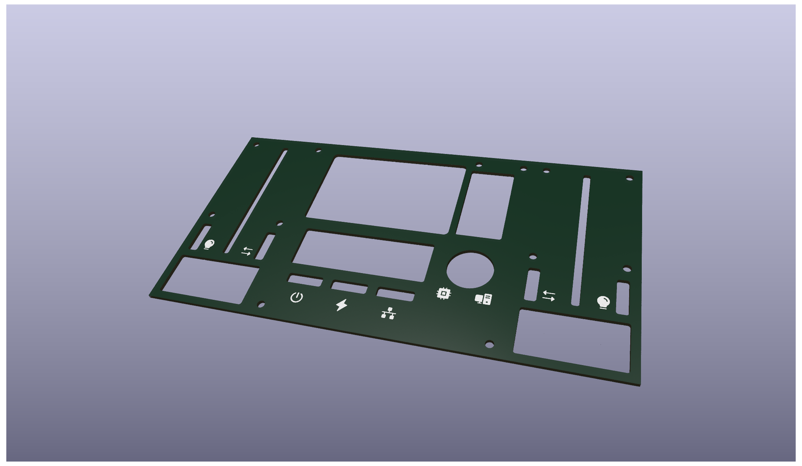
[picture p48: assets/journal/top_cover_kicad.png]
top cover in KiCAD


<sub>Time spent: 2.5 - Total: 37h</sub>

### 24/07/2025
**Log 16:** After I saw the 24$ cost estimate of the cover PCB, I decided to split it up into three parts: 2x side cover, 1x center cover, just as I originally planned.

<sub>Time spent: 0.5h - Total: 37.5h</sub>

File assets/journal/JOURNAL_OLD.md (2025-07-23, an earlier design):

## 18/06/2025
Log 1 *(1.5h)*: 
Today I started work on the new throttle, which will be the main way to control the model railroad. It would be able to control two locomotives simultaneously and send commands over LCC/CAN to the command station (Arduino Mega running DCC-EX on a custom PCB). It uses the same LCC/CAN bus as all I/O extension boards (also custom PCBs).
The throttle itself is going to be stationary and 3d-printed. The physical parts will be modular and designed to connect to a central "throttle-PCB" .

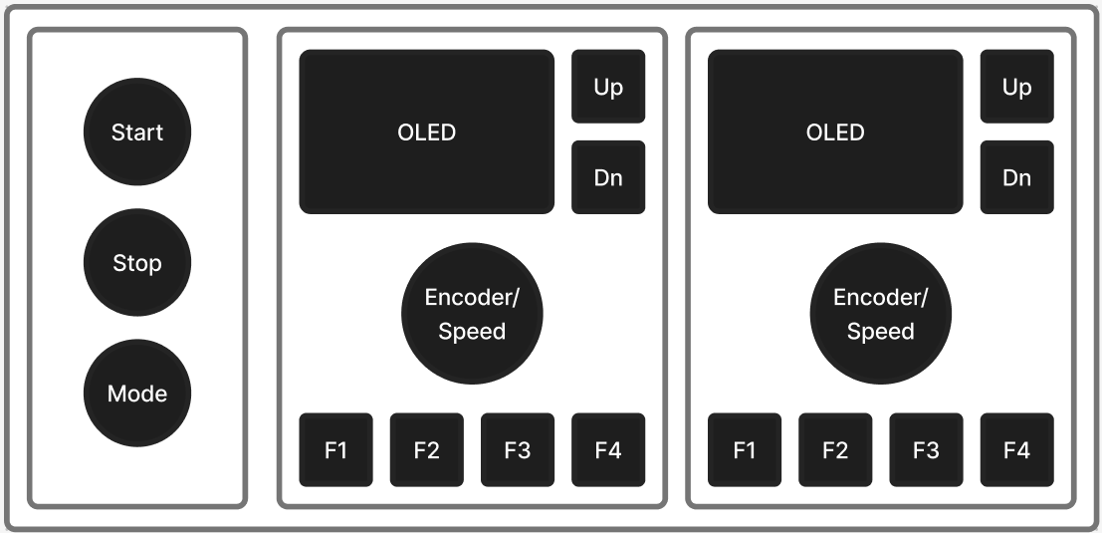
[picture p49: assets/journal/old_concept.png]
concept
**Throttle Design:**
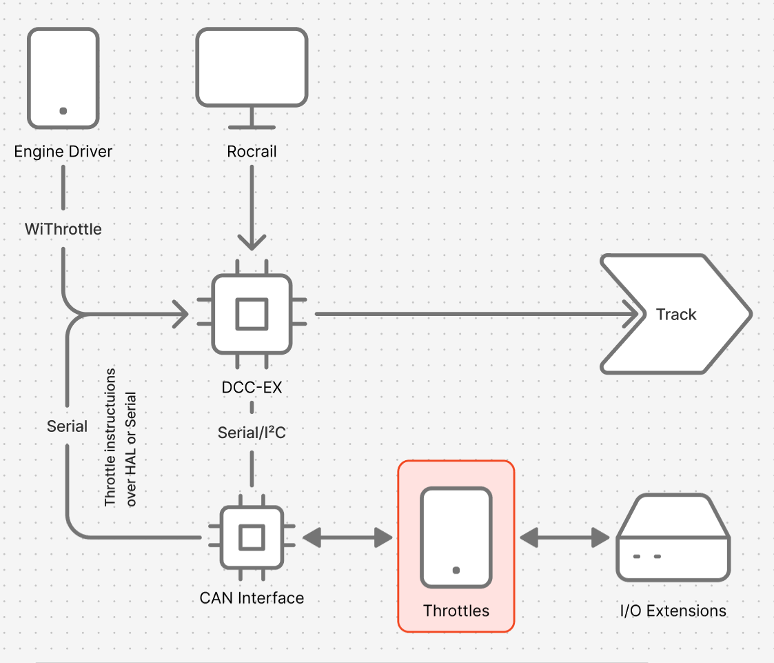
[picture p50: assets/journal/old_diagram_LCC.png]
model railroad diagram
**Architecture:** 

Because DCC-EX only accepts throttle commands over a separate serial port, an active CAN-Interface is required to distinguish between I/O and throttle messages and route them to different ports to the command station (DCC-EX).

## 19/06/2025
Log 2 *(2.5h)*:
I looked at different hardware options:
#### 1. MCU
I will probably use an ATmega-328p as microcontroller just because it can be easily programmed using an existing Arduino Uno and doesn’t require a separate programmer. Hopefully it has enough computing power to run two OLEDs and the CAN connection all at the same time. To be able to read ~40 inputs, shift registers have to be used.
#### 2. Inputs/Outputs

| Type | |
| --- | --- |
| Buttons | 12x Key Switches + Keycaps<br>3x 22mm  Industrial Push Buttons to turn on and off the track power and change the operating mode (auto/manual) |
| Dial | Rotary encoder to avoid conflicts when dial position doesn’t match locomotive speed |
| Display | 2x 0.96in I²C OLEDs |
| LEDs | multiple WS2812b-LEDs to show throttle and track status |
#### 3. Connectors

| Connection | Connector |
| --- | --- |
| LCC/CAN | 4x RJ45 ports - two of them can be used to connect mobile throttles **(CAN stub lenght!!!)** |
| Inputs | ~40x Wago 2601 |
| Displays | JST-PH or Wago 2601 |
| | |
#### 4. Shift registers
The 74HC165 has been selected because of its extensive documentation.
#### 5. CAN hardware
I’ve had good results using the MCP2515 CAN controller together with the TJA1050 CAN transceiver in previous projects, so I’ll use the same setup for this one.

### Log 3 *(1.5h)*: Rough sketch
![[Throttle v1.png]]
I created a very rough sketch to check button and display dimensions of the throttle. That’s when I noticed just how small 0.96 inches are. So I’ve decided to use a 1.54in OLED.

## 20/06/2025
### Log 4 *(1h)*:
I have updated the cost estimates and decided to switch from a 1.54in OLED to a 1.3in OLED. The smaller display is approximately half the cost.

### Log 5 (3h):
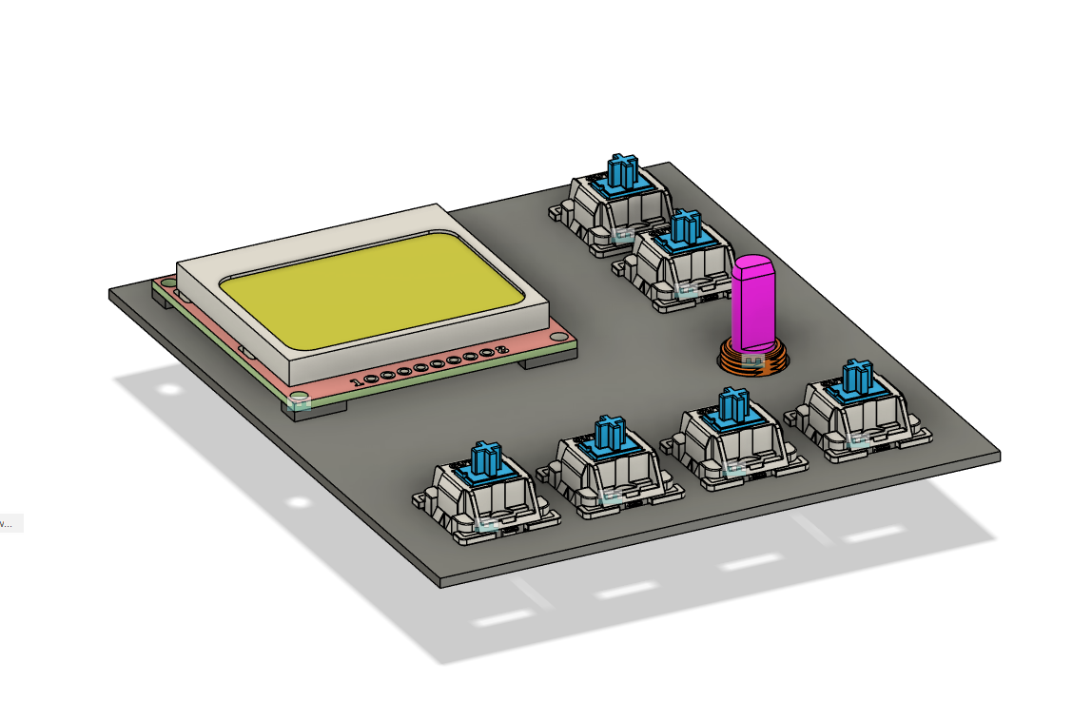
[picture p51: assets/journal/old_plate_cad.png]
plate in CAD

I have begun working on the mounting plate. All inputs and the display are attached to it, and it's covered by a front panel (aluminum PCB).

## 21/06/2025
### Log 6 (6h)
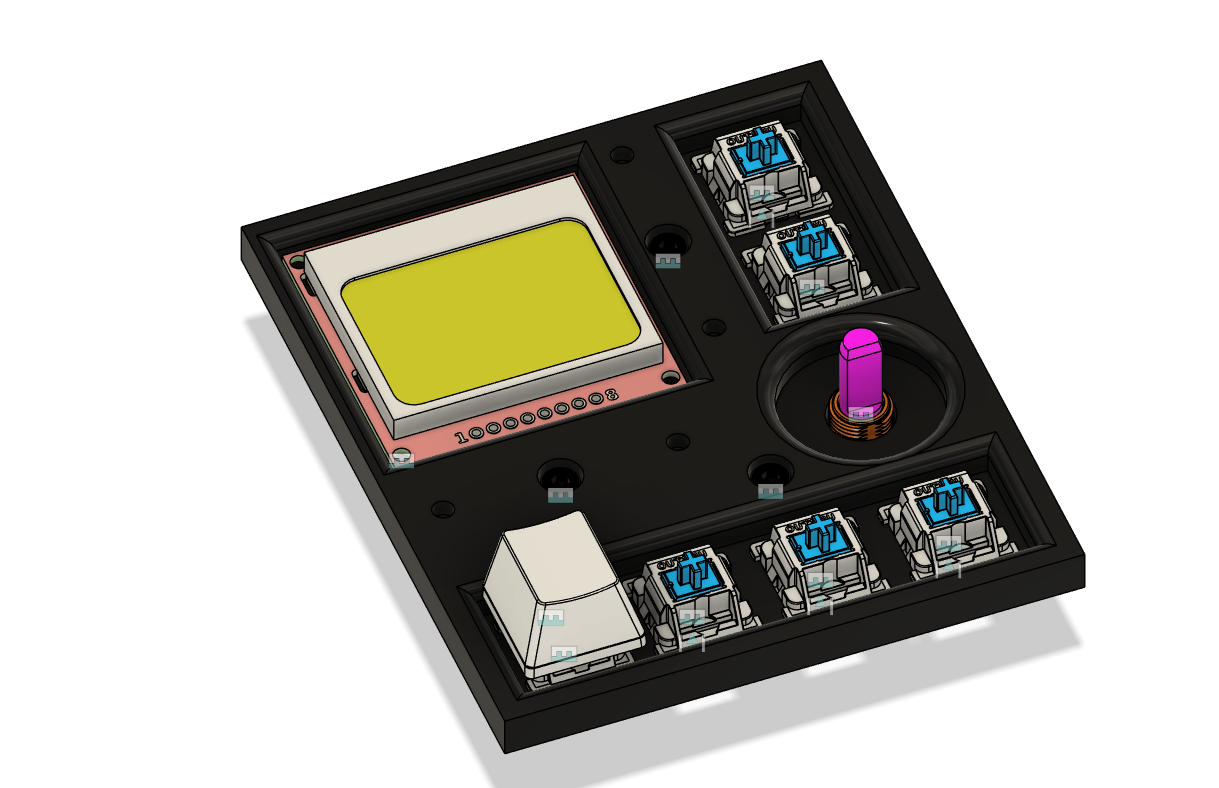
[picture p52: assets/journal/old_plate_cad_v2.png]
next version of this plate

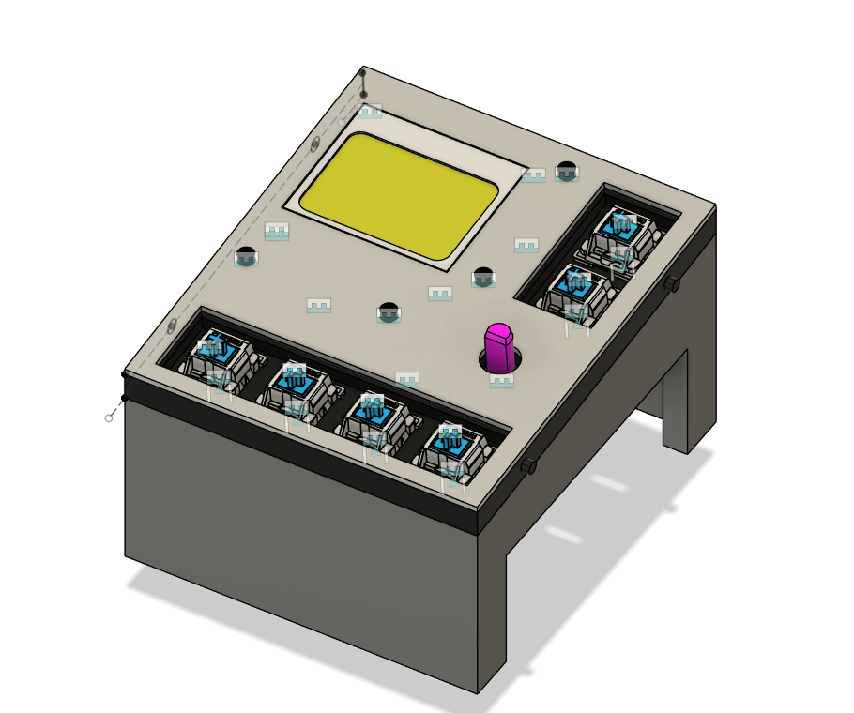
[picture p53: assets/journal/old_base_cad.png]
base design

With the base plate (basically) finished, I started working on the base piece. Its main task is to hold the PCB securely beneath the inputs. It will preferably be a pain fiddling all cables from the switches, etc. through but that’s future me’s problem.

## 23/06/2025
### Log 8: *(3h)*
I started working on the PCBs schematic. Most CAN-related parts I could easily copy from a previous project, which accelerated the process by a lot. I decided against the use of shift registers for all inputs and decided on I²C I/O expanders simply because they can call an interrupt.
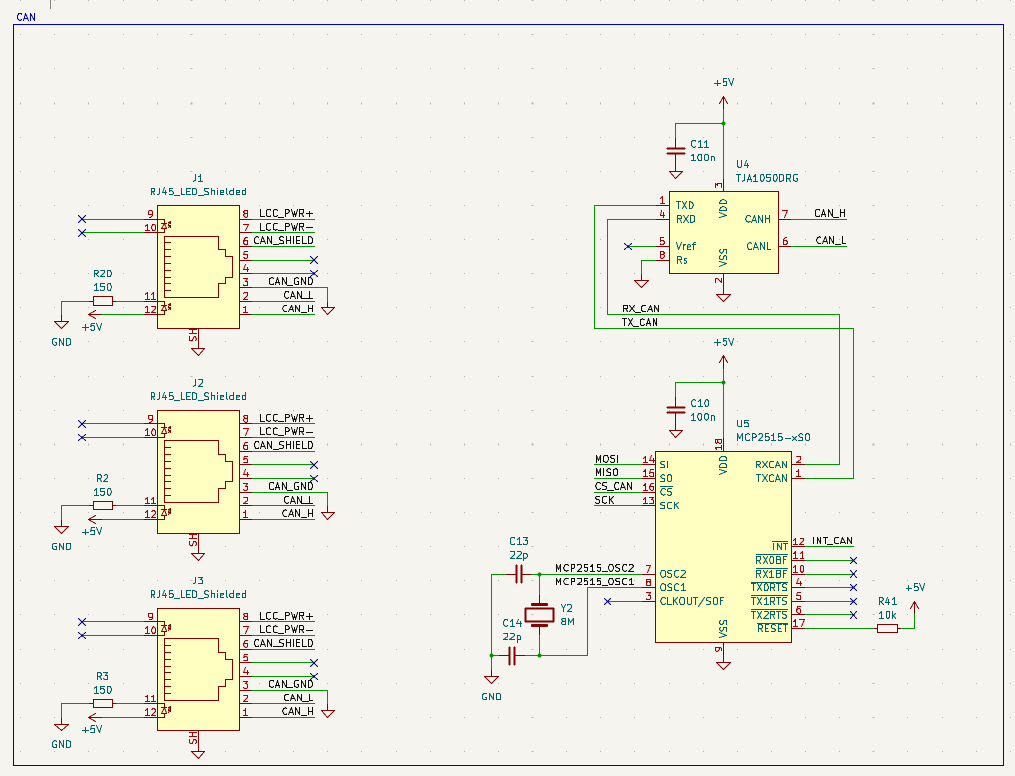
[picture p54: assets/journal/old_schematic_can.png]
CAN schematic

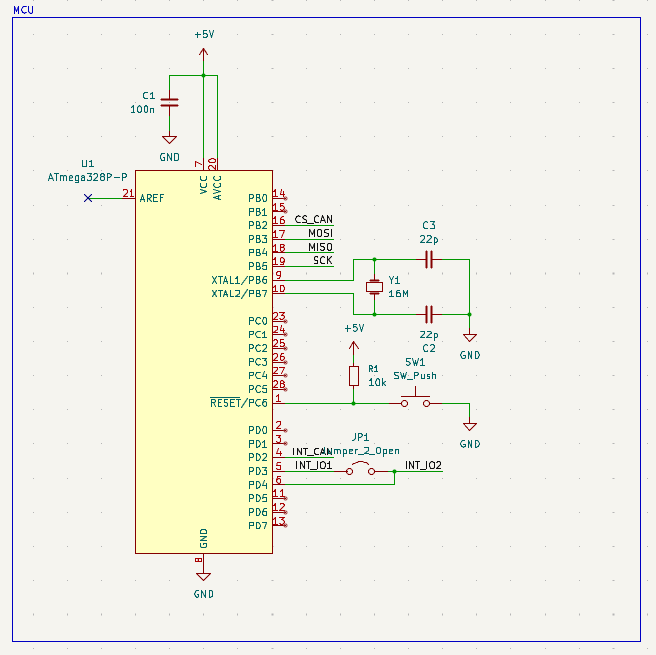
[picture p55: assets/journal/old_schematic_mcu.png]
MCU schematic

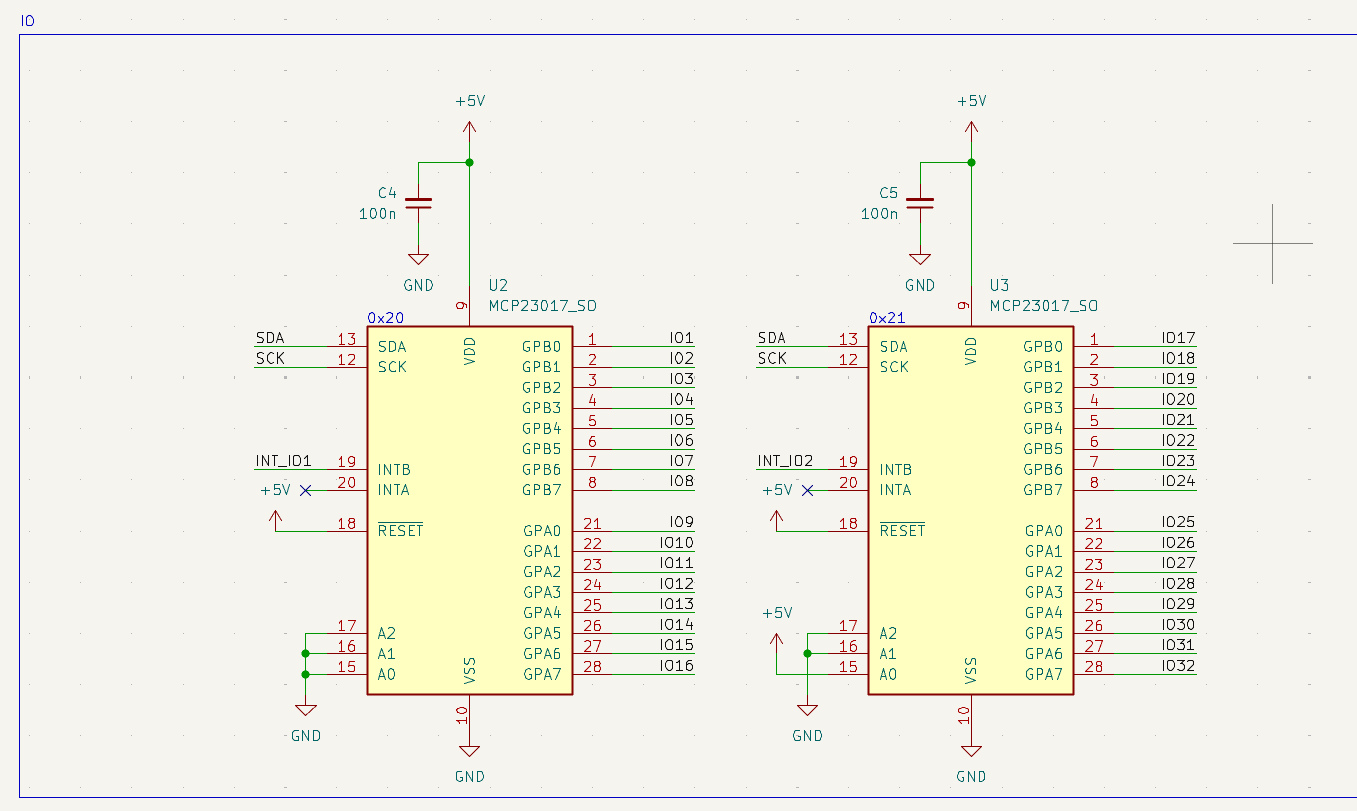
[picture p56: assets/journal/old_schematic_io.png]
I/O expanders schematic

### Log 9: *(1.5h)*
I further worked on the cost estimate, which now sits at ~80€. Because I already have the WAGO connectors, it’s ~20€ cheaper, so ~50€ + shipping = 70€.

## 25/06/2025
### Log 10: *(2.25h)*
Today I managed to finish the schematic. The biggest challenge was definitely the level shifters. I started with an 8-channel bi-directional shifter, but I couldn’t find one that could be hand-soldered. I therefore ended up with a simple MOSFET-based design.
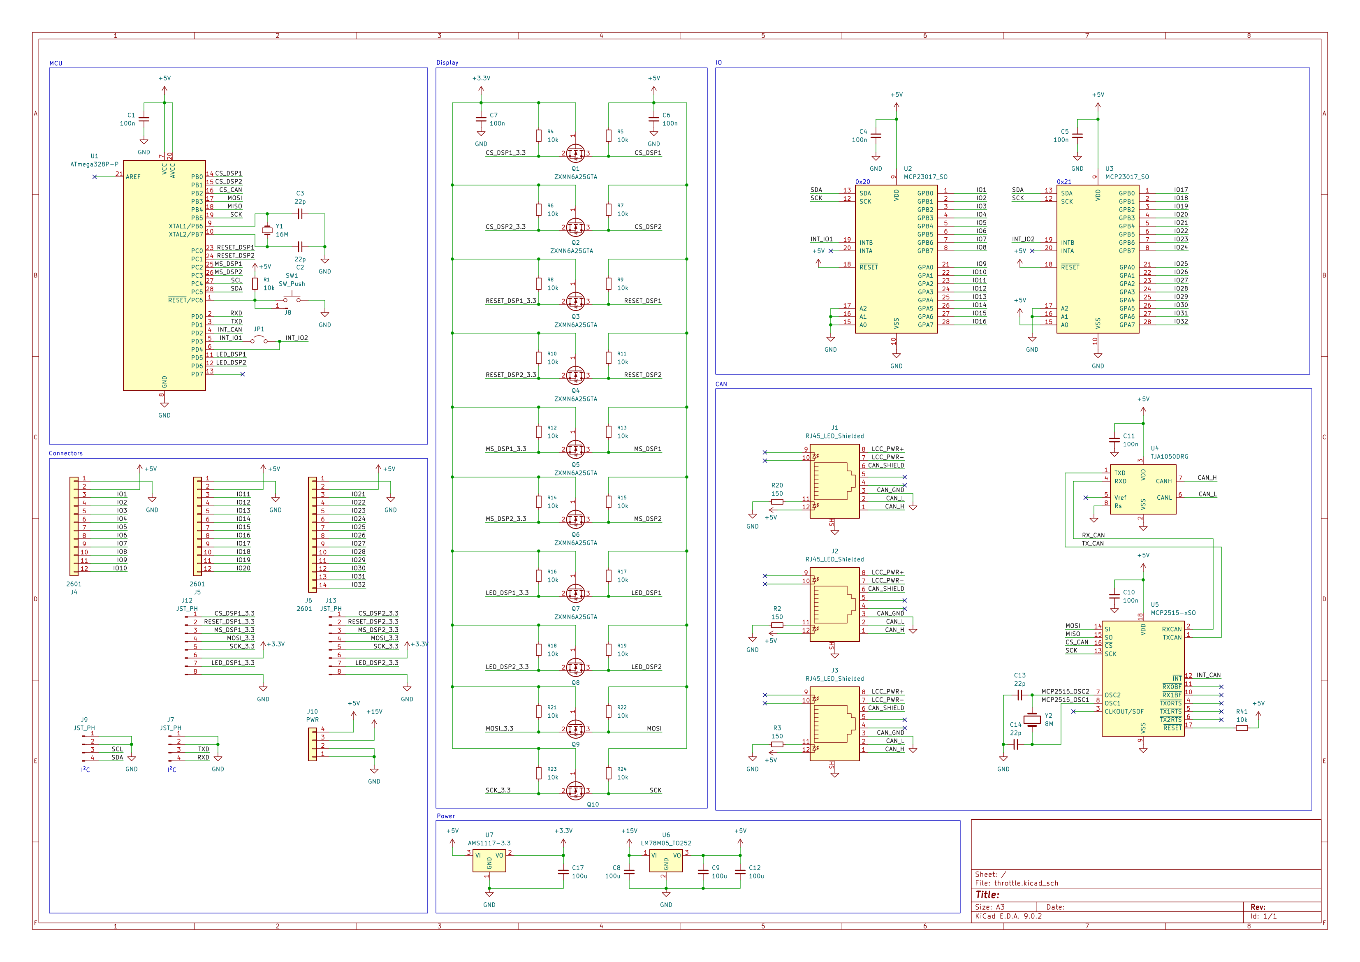
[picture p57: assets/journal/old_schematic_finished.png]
finished schematic


## 26/06/2025
### Log 11: (2.5h)
All footprints assigned🎉🎉🎉! Because I didn’t have my KiCAD library with me, which included many of the components I used, I had to reimport and partially recreate most of them. I also got started on the rough PCB layout:
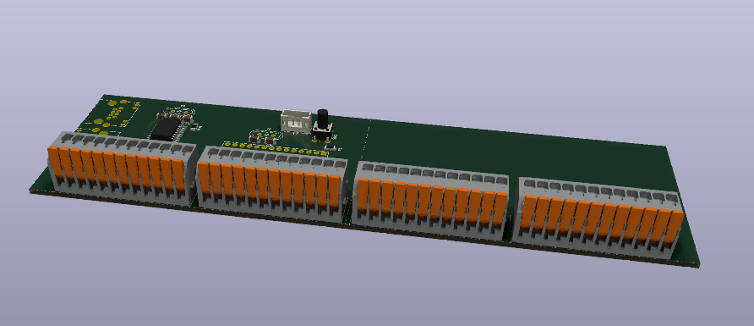
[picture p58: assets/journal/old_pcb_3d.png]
rough PCB layout


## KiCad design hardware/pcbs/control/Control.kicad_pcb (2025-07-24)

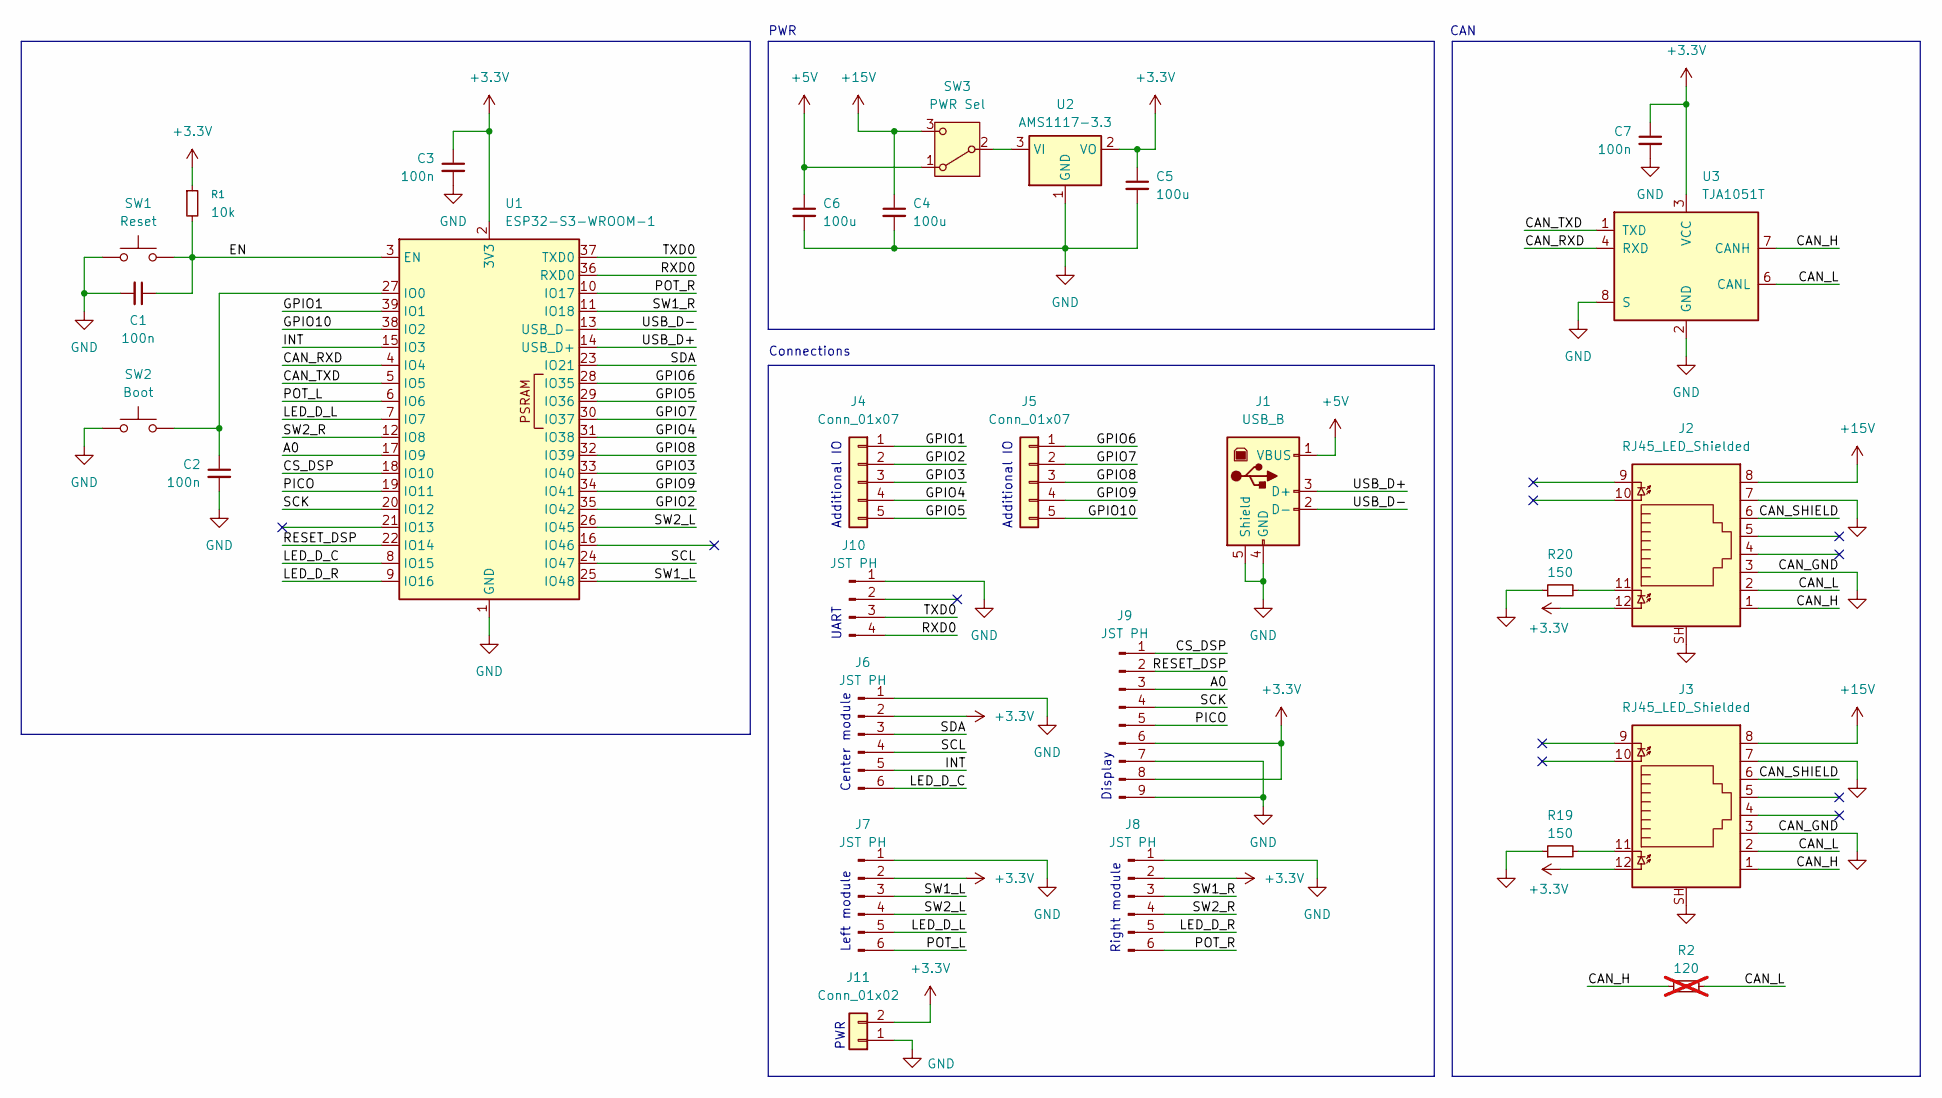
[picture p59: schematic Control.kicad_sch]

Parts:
C1, C2, C3, C7: 100n; C_1206_3216Metric
C4, C5, C6: 100u; C_Radial_D6.3mm_H7.0mm_P2.50mm
J1: USB_B; TE Connectivity_292304_USB_B
J2, J3: RJ45_LED_Shielded; PHOENIX_1337243; LCSC C386757
J4, J5: Conn_01x07; TerminalBlock_WAGO_2601-3105_1x05_P3.50mm_Vertical
J6, J7, J8: JST PH; JST_PH_B6B-PH-K_1x06_P2.00mm_Vertical
J9: JST PH; JST_PH_B9B-PH-K_1x09_P2.00mm_Vertical
J10: JST PH; JST_PH_B4B-PH-K_1x04_P2.00mm_Vertical
J11: Conn_01x02; TerminalBlock_WAGO_2601-3102_1x02_P3.50mm_Vertical
R1: 10k; R_1206_3216Metric
R2: 120; R_Axial_DIN0207_L6.3mm_D2.5mm_P7.62mm_Horizontal; not fitted
R19, R20: 150; R_1206_3216Metric; LCSC C2907432
SW1: Reset; SW-SMD_L3.9-W3.0-P4.45
SW2: Boot; SW-SMD_L3.9-W3.0-P4.45
SW3: PWR Sel; SW-TH_SS13E05LX
U1: ESP32-S3-WROOM-1; ESP32-S3-WROOM-1U
U2: AMS1117-3.3; SOT-223-3_TabPin2
U3: TJA1051T; SOIC-8_3.9x4.9mm_P1.27mm

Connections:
+3.3V: C3.1, C5.1, C7.1, J2.12, J3.12, J6.2, J7.2, J8.2, J9.6, J9.8, J11.2, R1.1, U1.2 (3V3), U2.2 (VO), U3.3 (VCC)
+5V: C6.1, J1.1 (VBUS), SW3.1 (A)
+15V: C4.1, J2.8, J3.8, SW3.3 (C)
/A0: J9.3, U1.17 (IO9)
/CAN_H: J2.1, J3.1, R2.1, U3.7 (CANH)
/CAN_L: J2.2, J3.2, R2.2, U3.6 (CANL)
/CAN_RXD: U1.4 (IO4), U3.4 (RXD)
/CAN_SHIELD: J2.6, J3.6
/CAN_TXD: U1.5 (IO5), U3.1 (TXD)
/CS_DSP: J9.1, U1.18 (IO10)
/EN: C1.1, R1.2, SW1.2, U1.3 (EN)
/GPIO1: J4.1, U1.39 (IO1)
/GPIO2: J4.2, U1.35 (IO42)
/GPIO3: J4.3, U1.33 (IO40)
/GPIO4: J4.4, U1.31 (IO38)
/GPIO5: J4.5, U1.29 (IO36)
/GPIO6: J5.1, U1.28 (IO35)
/GPIO7: J5.2, U1.30 (IO37)
/GPIO8: J5.3, U1.32 (IO39)
/GPIO9: J5.4, U1.34 (IO41)
/GPIO10: J5.5, U1.38 (IO2)
/INT: J6.5, U1.15 (IO3)
/LED_D_C: J6.6, U1.8 (IO15)
/LED_D_L: J7.5, U1.7 (IO7)
/LED_D_R: J8.5, U1.9 (IO16)
/PICO: J9.5, U1.19 (IO11)
/POT_L: J7.6, U1.6 (IO6)
/POT_R: J8.6, U1.10 (IO17)
/RESET_DSP: J9.2, U1.22 (IO14)
/RXD0: J10.4, U1.36 (RXD0)
/SCK: J9.4, U1.20 (IO12)
/SCL: J6.4, U1.24 (IO47)
/SDA: J6.3, U1.23 (IO21)
/SW1_L: J7.3, U1.25 (IO48)
/SW1_R: J8.3, U1.11 (IO18)
/SW2_L: J7.4, U1.26 (IO45)
/SW2_R: J8.4, U1.12 (IO8)
/TXD0: J10.3, U1.37 (TXD0)
/USB_D+: J1.3 (D+), U1.14 (USB_D+)
/USB_D-: J1.2 (D-), U1.13 (USB_D-)
GND: C1.2, C2.2, C3.2, C4.2, C5.2, C6.2, C7.2, J1.4 (GND), J1.5 (Shield), J2.3, J2.7, J2.SH, J3.3, J3.7, J3.SH, J6.1, J7.1, J8.1, J9.7, J9.9, J10.1, J11.1, R19.1, R20.1, SW1.1, SW2.1, U1.1 (GND), U1.40 (GND), U1.41 (GND), U2.1 (GND), U3.2 (GND), U3.8 (S)
unnamed: J2.11, R20.2
unnamed: J3.11, R19.2
unnamed: SW3.2 (B), U2.3 (VI)
unnamed: C2.1, SW2.2, U1.27 (IO0)

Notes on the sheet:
UART
Additional IO
Center module
CAN
PWR
Left module
Display
Right module
Connections

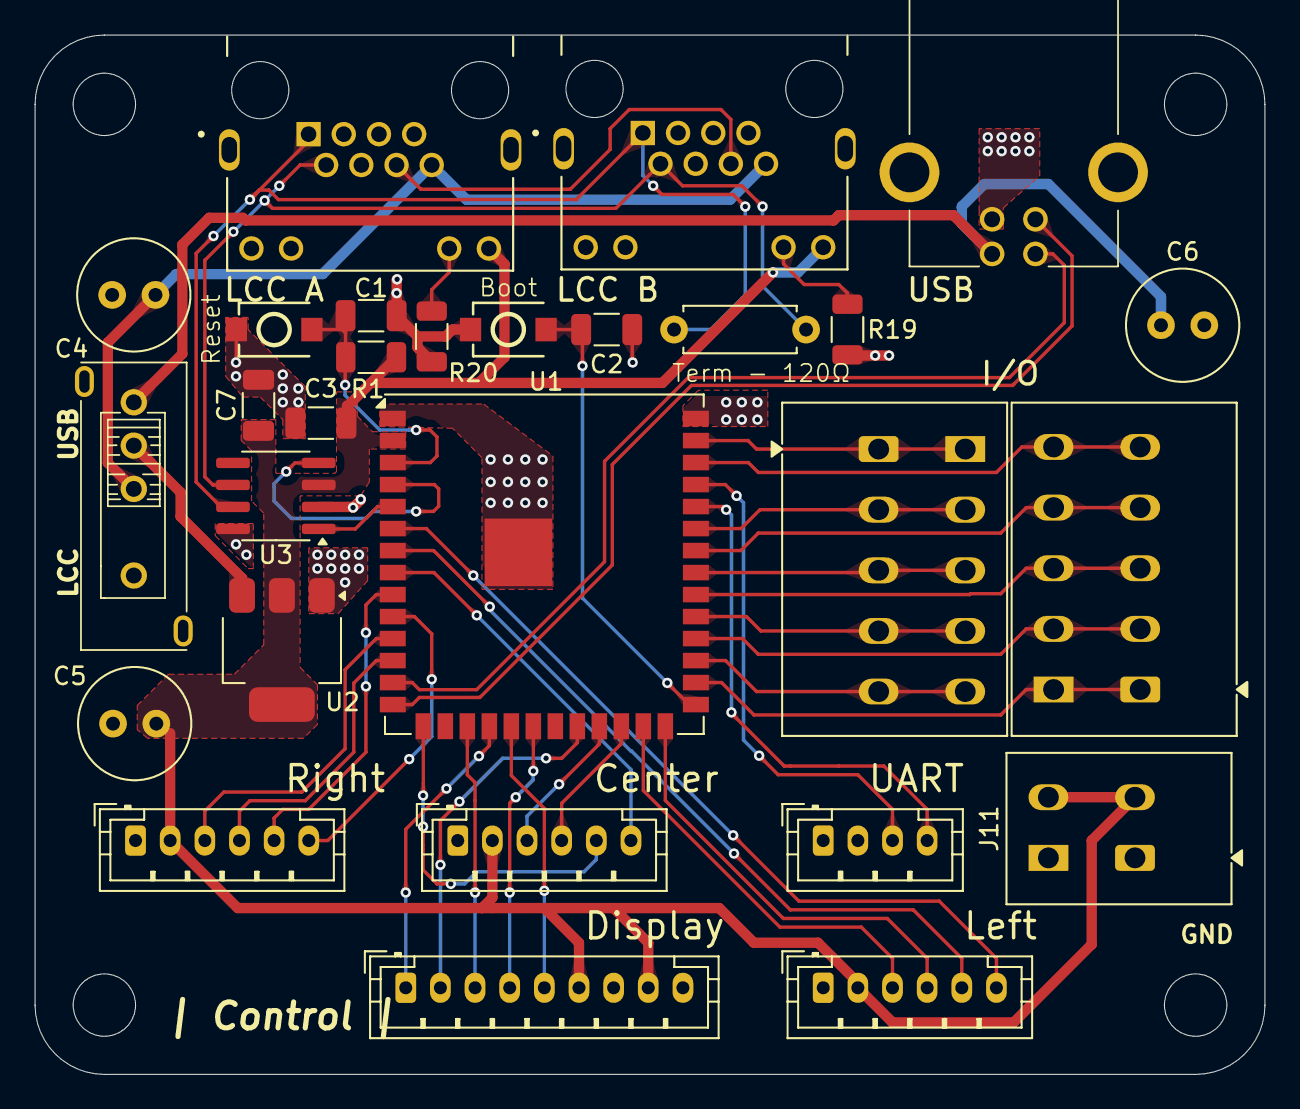
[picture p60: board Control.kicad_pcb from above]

Board: 2 copper layers, 71.0 x 60.0 mm, 28 parts (0 on the bottom side), 45 nets.

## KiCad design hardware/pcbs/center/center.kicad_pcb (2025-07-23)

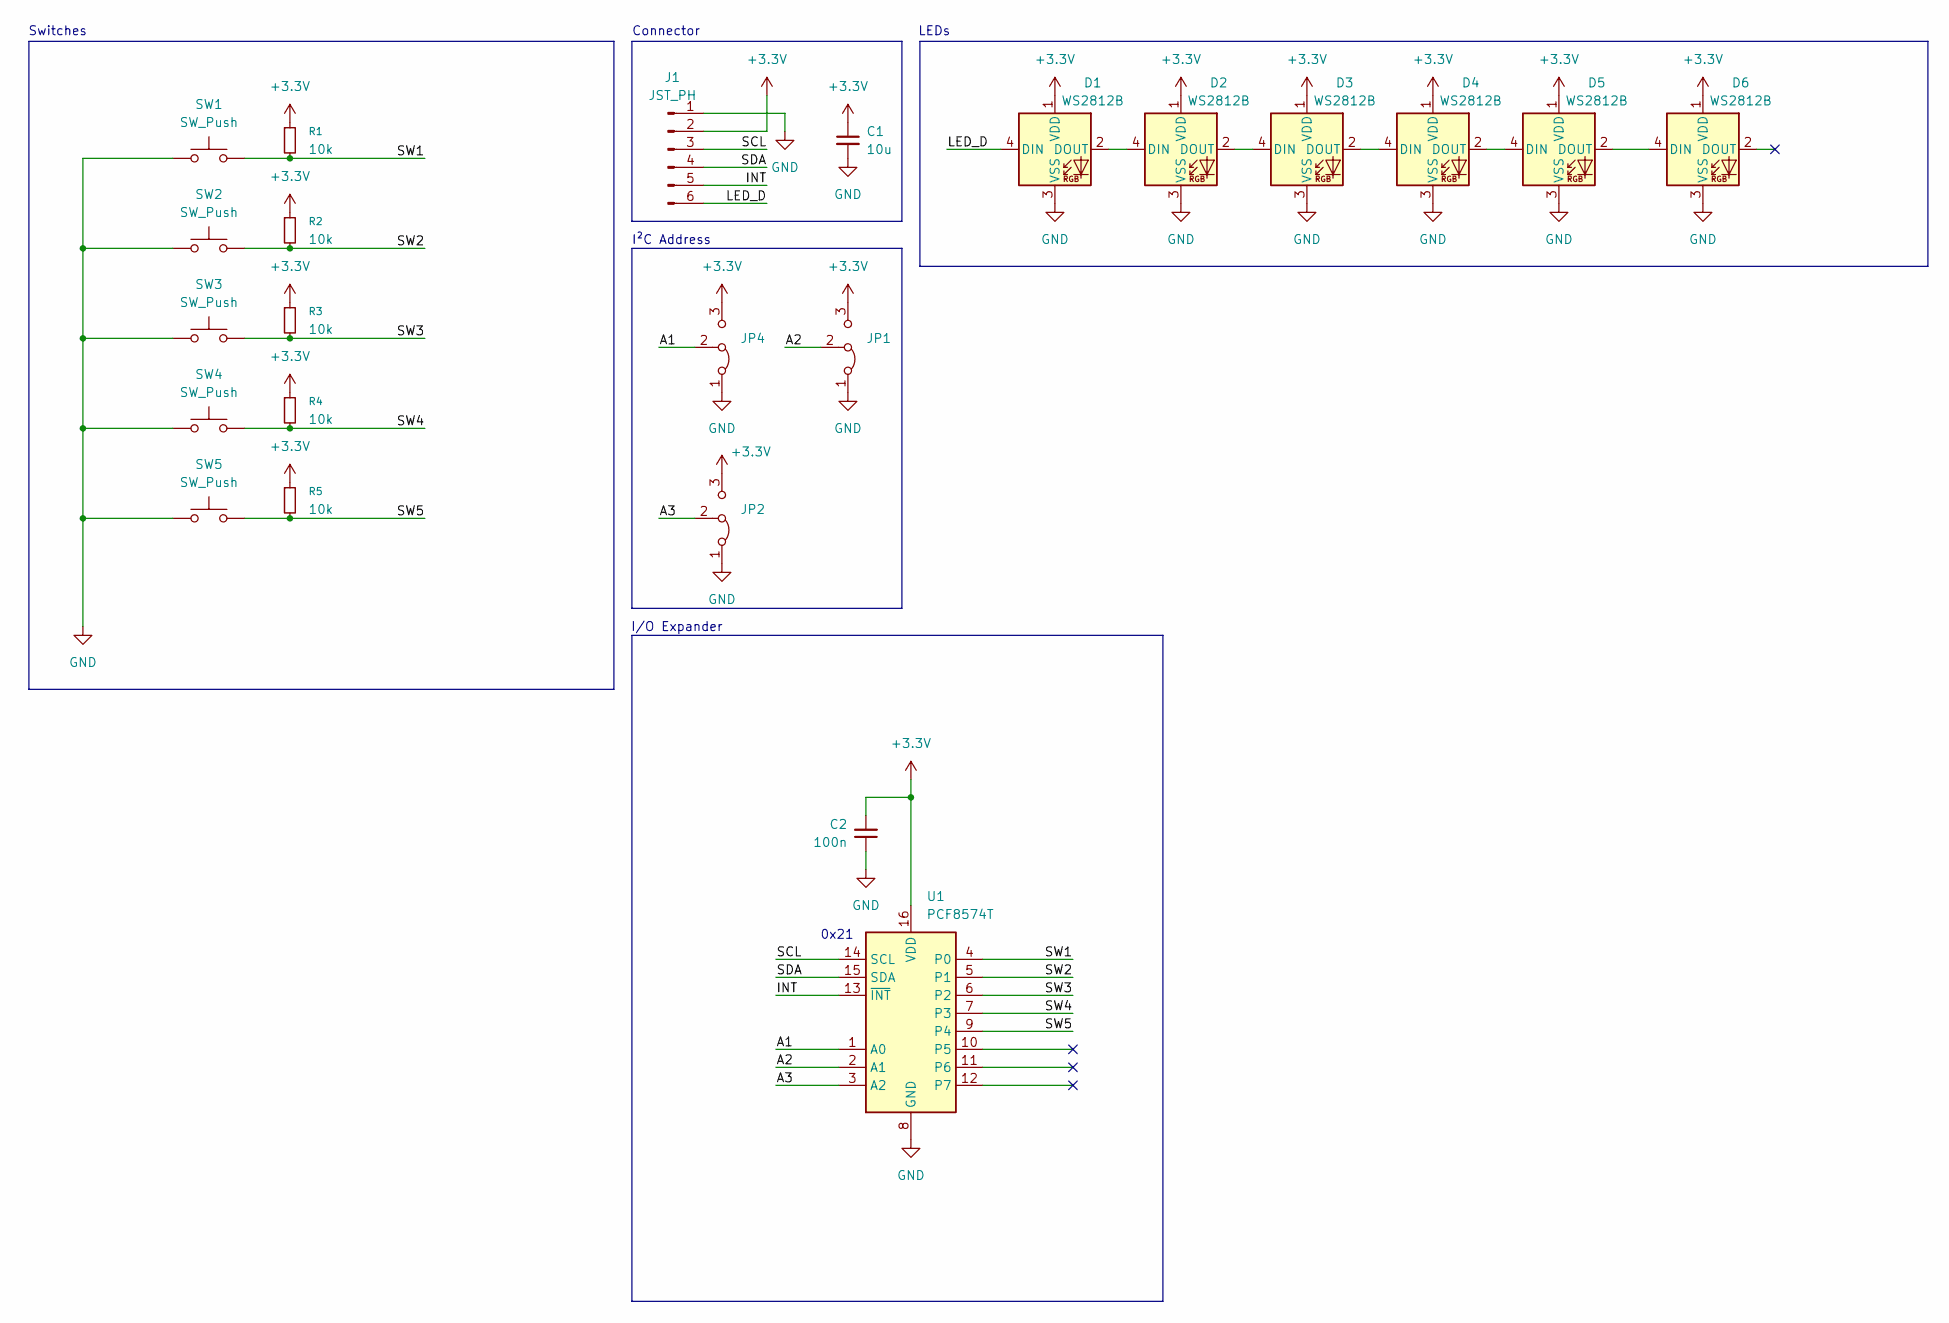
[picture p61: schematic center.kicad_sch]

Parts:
C1: 10u; C_Radial_D6.3mm_H11.0mm_P2.50mm
C2: 100n; C_1206_3216Metric
D1, D2, D3, D4, D5, D6: WS2812B; LED_WS2812B_PLCC4_5.0x5.0mm_P3.2mm
J1: JST_PH; JST_PH_B6B-PH-K_1x06_P2.00mm_Vertical
JP1, JP2, JP4: Jumper_3_Bridged12; SolderJumper-3_P1.3mm_Bridged2Bar12_Pad1.0x1.5mm
R1, R2, R3, R4, R5: 10k; R_1206_3216Metric
SW1, SW2, SW3, SW4, SW5: SW_Push; SW_Cherry_MX_1.00u_PCB
U1: PCF8574T; SOIC-16W_7.5x10.3mm_P1.27mm

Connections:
+3.3V: C1.1, C2.2, D1.1 (VDD), D2.1 (VDD), D3.1 (VDD), D4.1 (VDD), D5.1 (VDD), D6.1 (VDD), J1.2, JP1.3 (B), JP2.3 (B), JP4.3 (B), R1.1, R2.1, R3.1, R4.1, R5.1, U1.16 (VDD)
/A1: JP4.2 (C), U1.1 (A0)
/A2: JP1.2 (C), U1.2 (A1)
/A3: JP2.2 (C), U1.3 (A2)
/INT: J1.5, U1.13 (~INT)
/LED_D: D1.4 (DIN), J1.6
/SCL: J1.3, U1.14 (SCL)
/SDA: J1.4, U1.15 (SDA)
/SW1: R1.2, SW1.2, U1.4 (P0)
/SW2: R2.2, SW2.2, U1.5 (P1)
/SW3: R3.2, SW3.2, U1.6 (P2)
/SW4: R4.2, SW4.2, U1.7 (P3)
/SW5: R5.2, SW5.2, U1.9 (P4)
GND: C1.2, C2.1, D1.3 (VSS), D2.3 (VSS), D3.3 (VSS), D4.3 (VSS), D5.3 (VSS), D6.3 (VSS), J1.1, JP1.1 (A), JP2.1 (A), JP4.1 (A), SW1.1, SW2.1, SW3.1, SW4.1, SW5.1, U1.8 (GND)
unnamed: D1.2 (DOUT), D2.4 (DIN)
unnamed: D2.2 (DOUT), D3.4 (DIN)
unnamed: D3.2 (DOUT), D4.4 (DIN)
unnamed: D4.2 (DOUT), D5.4 (DIN)
unnamed: D5.2 (DOUT), D6.4 (DIN)

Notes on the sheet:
0x21
I/O Expander
LEDs
I²C Address
Connector
Switches

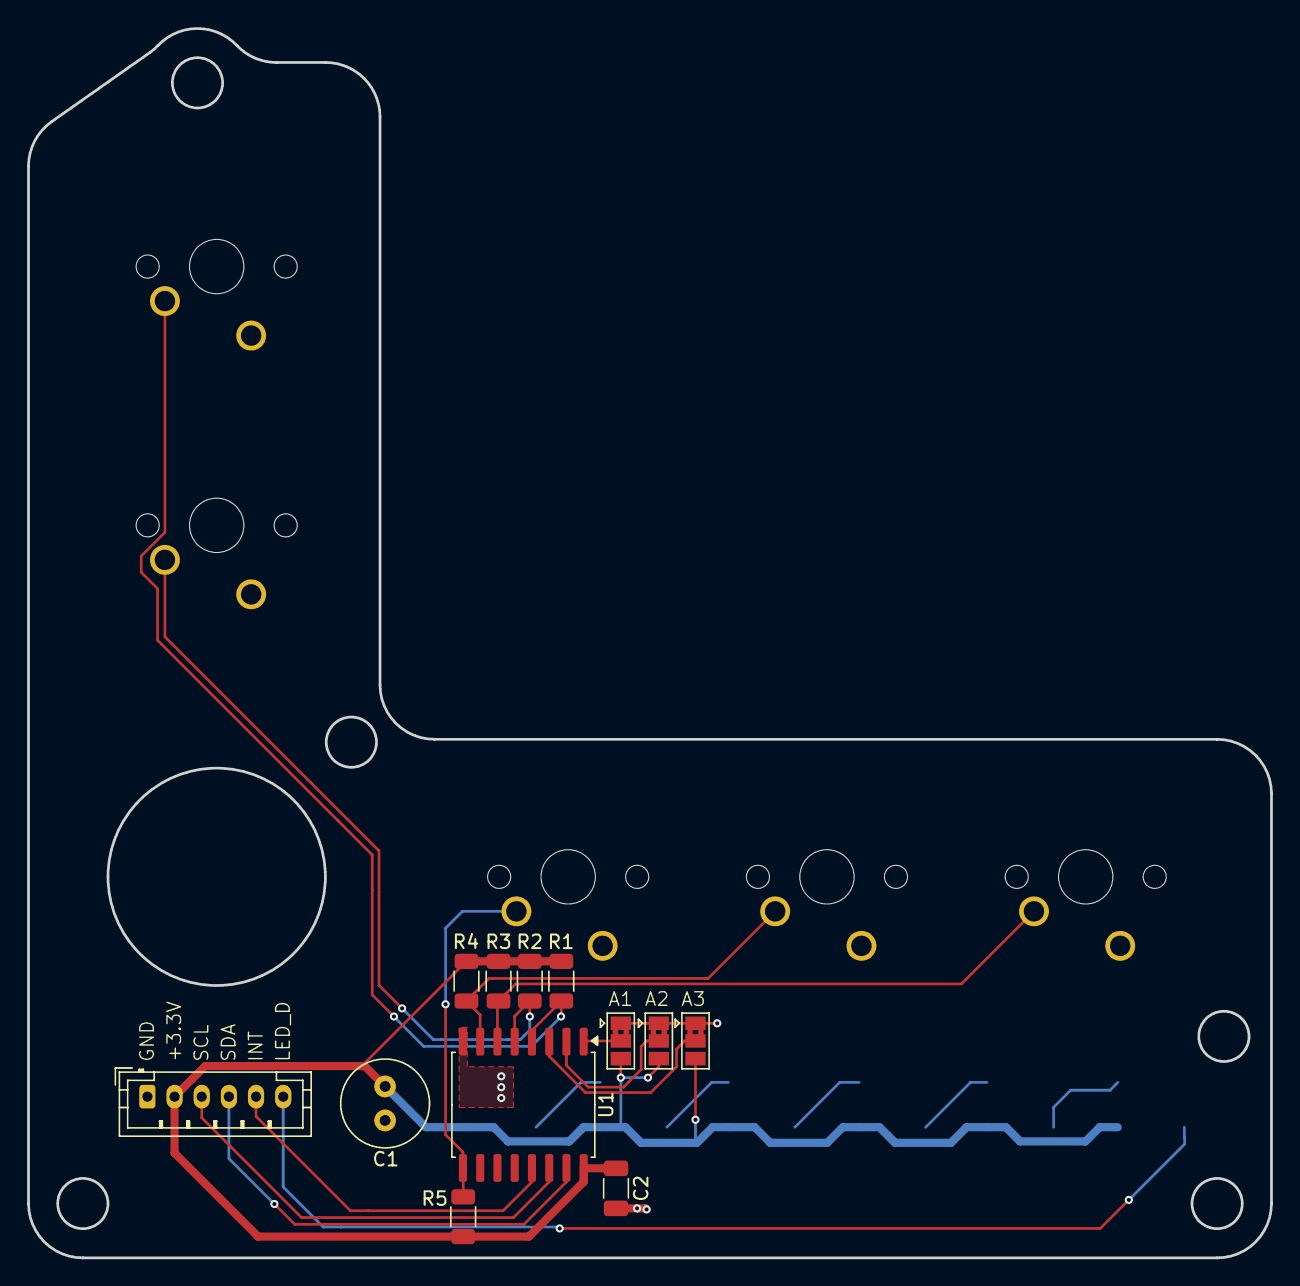
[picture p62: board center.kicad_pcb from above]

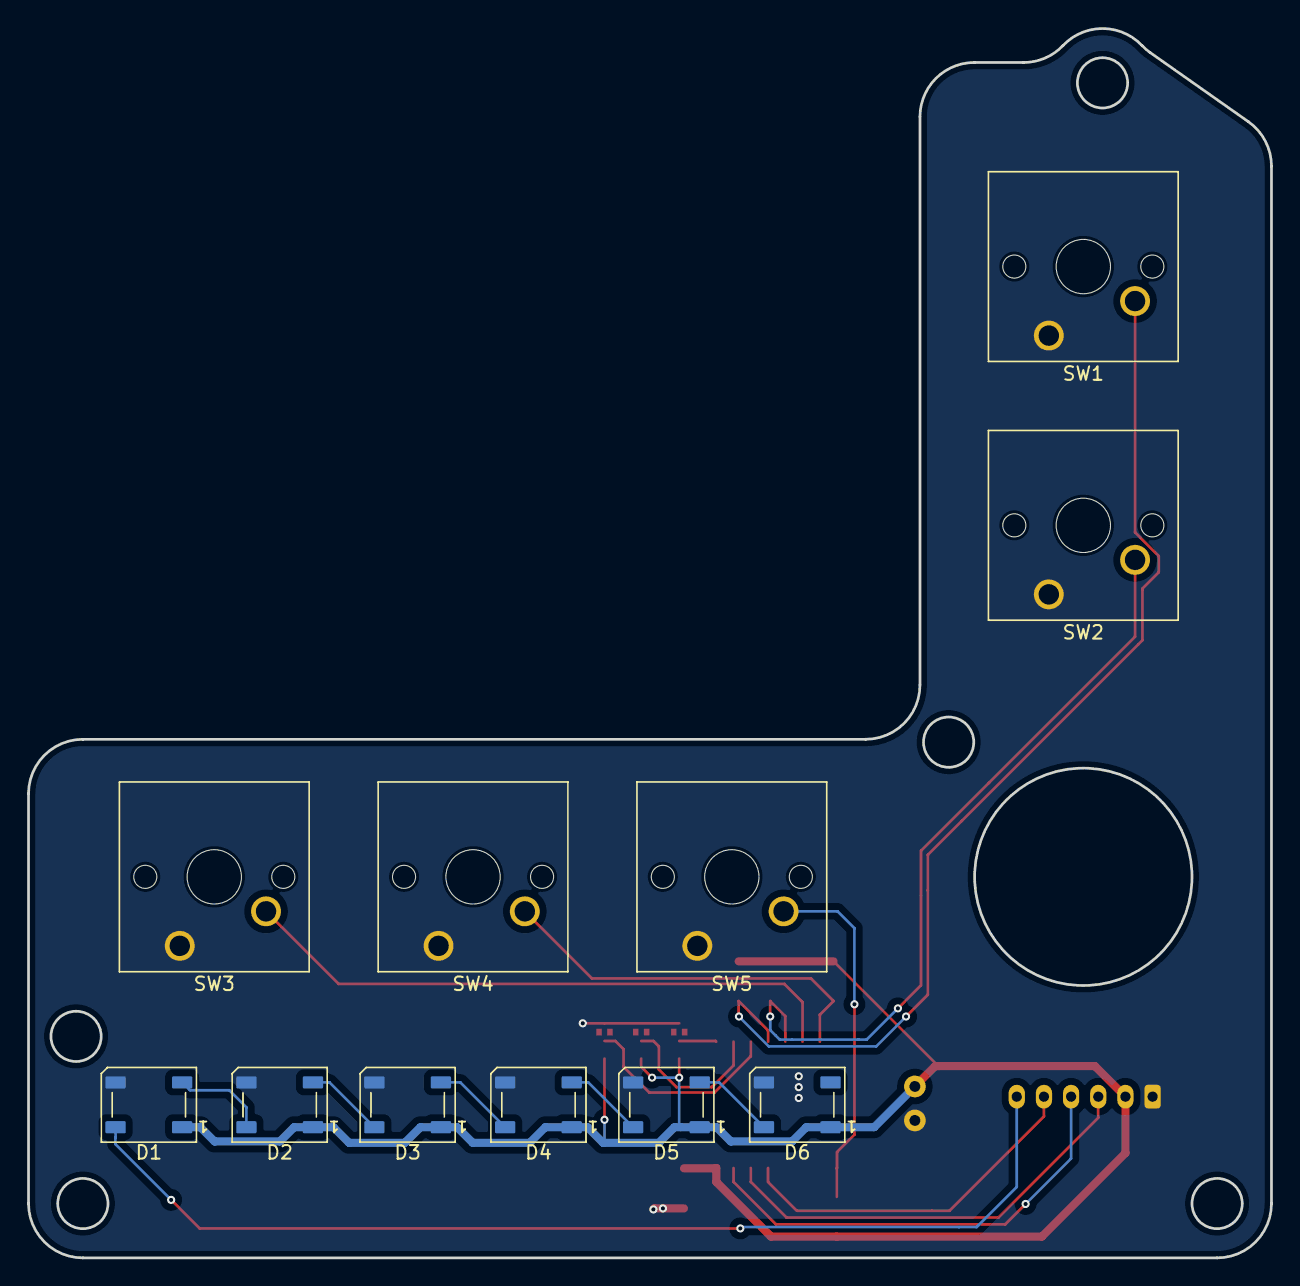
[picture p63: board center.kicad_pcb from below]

Board: 2 copper layers, 91.5 x 90.5 mm, 23 parts (11 on the bottom side), 19 nets.

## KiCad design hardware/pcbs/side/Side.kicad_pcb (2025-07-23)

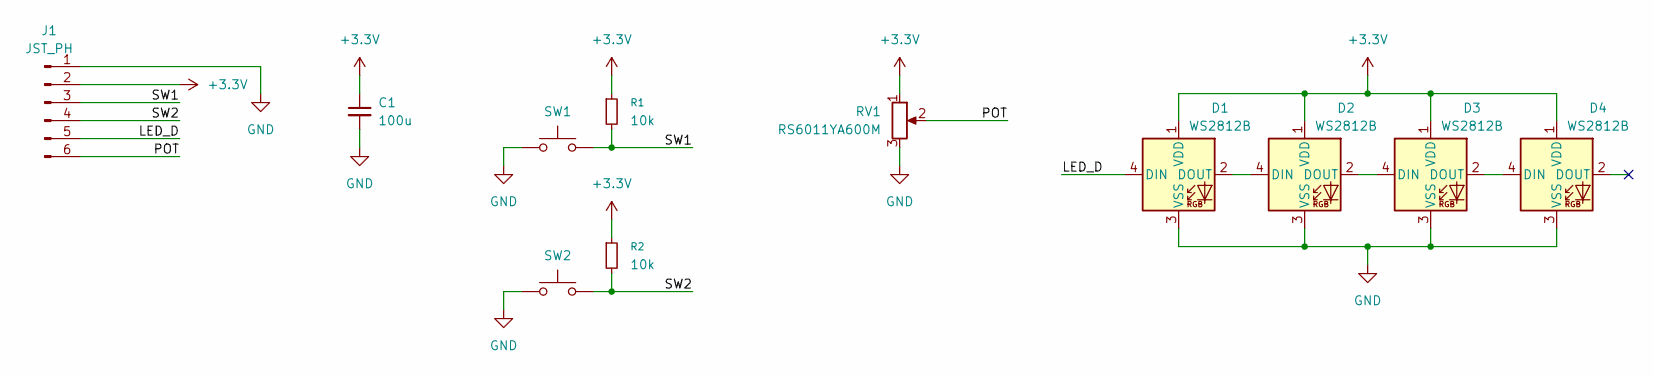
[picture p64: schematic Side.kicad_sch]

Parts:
C1: 100u; C_Radial_D6.3mm_H7.0mm_P2.50mm
D1, D2, D3, D4: WS2812B; LED_WS2812B_PLCC4_5.0x5.0mm_P3.2mm
J1: JST_PH; JST_PH_B6B-PH-K_1x06_P2.00mm_Vertical
R1, R2: 10k; R_1206_3216Metric
RV1: RS6011YA600M
SW1, SW2: SW_Push; SW_Cherry_MX_1.00u_PCB

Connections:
+3.3V: C1.1, D1.1 (VDD), D2.1 (VDD), D3.1 (VDD), D4.1 (VDD), J1.2, R1.1, R2.1, RV1.1
/LED_D: D1.4 (DIN), J1.5
/POT: J1.6, RV1.2
/SW1: J1.3, R1.2, SW1.2
/SW2: J1.4, R2.2, SW2.2
GND: C1.2, D1.3 (VSS), D2.3 (VSS), D3.3 (VSS), D4.3 (VSS), J1.1, RV1.3, SW1.1, SW2.1
unnamed: D1.2 (DOUT), D2.4 (DIN)
unnamed: D2.2 (DOUT), D3.4 (DIN)
unnamed: D3.2 (DOUT), D4.4 (DIN)

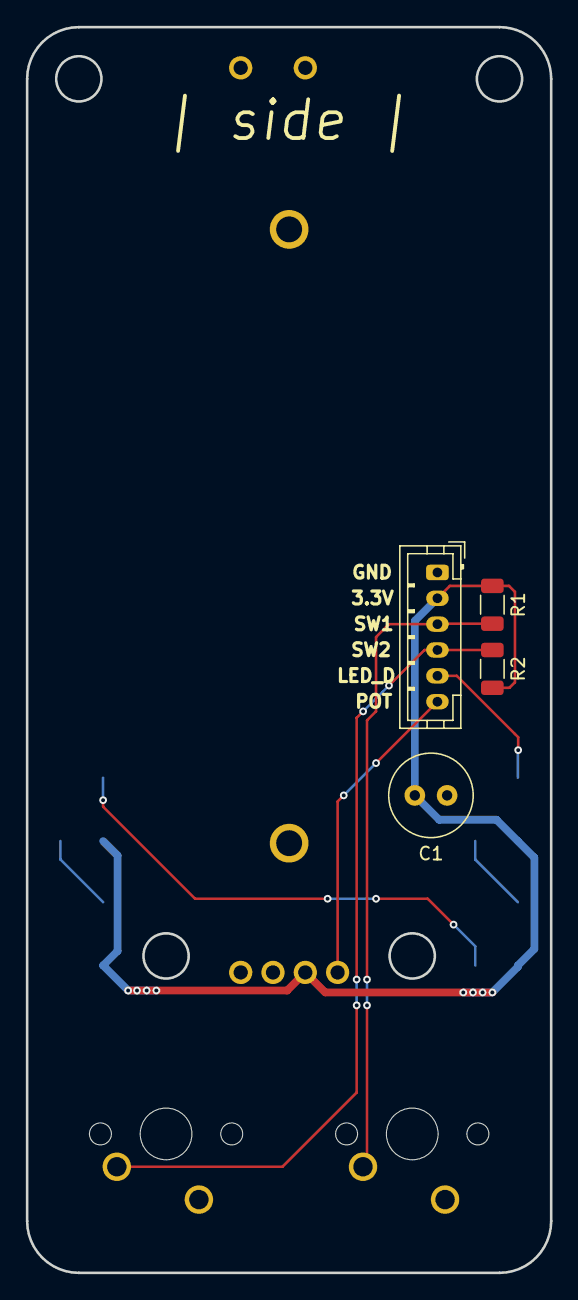
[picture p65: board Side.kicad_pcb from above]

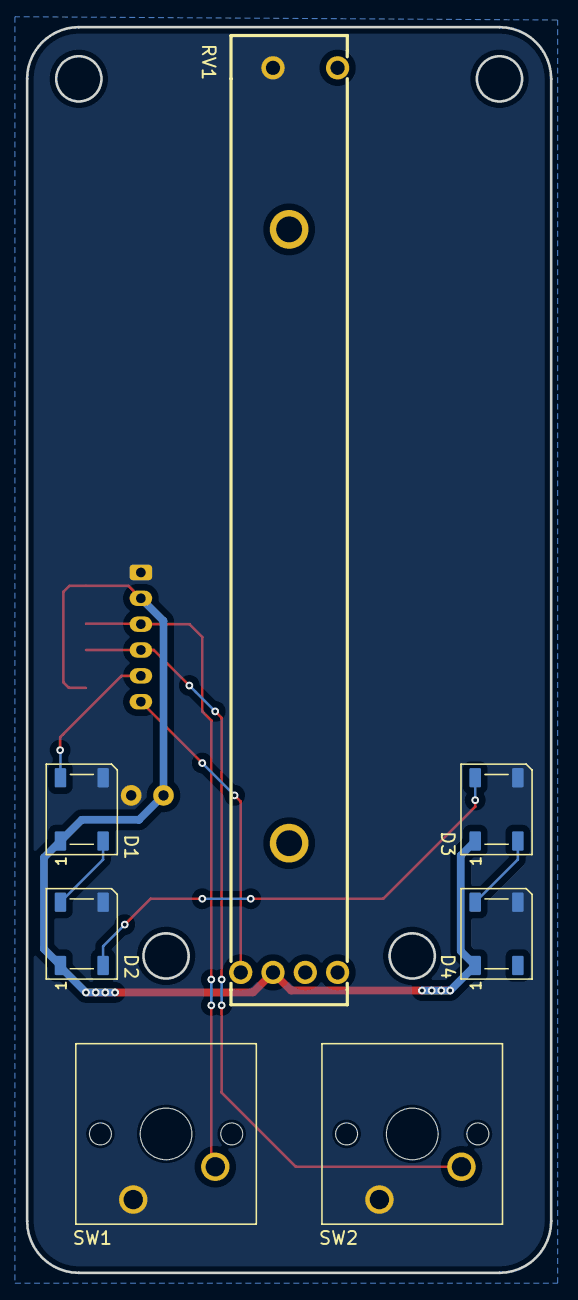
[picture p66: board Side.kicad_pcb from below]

Board: 2 copper layers, 40.6 x 96.4 mm, 11 parts (7 on the bottom side), 9 nets.

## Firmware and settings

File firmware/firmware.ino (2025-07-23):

#include <U8g2lib.h>
#include <ESP32-TWAI-CAN.hpp>
#include <PCF8574.h>
#include <Wire.h>
#include "screens.h"
#include "can_cmds.h"

#define BASE_ADDRESS 1
#define I2C_FREQ 400000
#define SDA 21
#define SCL 47
#define CS_DSP 10
#define PICO 11
#define SCK 12
#define A0 9
#define CAN_TX 5
#define CAN_RX 4
#define POTENTIOMETER_LOCO_1_PIN 6
#define POTENTIOMETER_LOCO_2_PIN 17
#define LIGHT_LOCO_1_PIN 48
#define LIGHT_LOCO_2_PIN 18
#define DIR_LOCO_1_PIN 45
#define DIR_LOCO_2_PIN 8

U8G2_ST7565_EA_DOGM128_1_4W_SW_SPI u8g2(U8G2_R0, SCK, PICO, CS_DSP, A0);
u8g2_uint_t offset;
u8g2_uint_t width;

TwoWire I2C = TwoWire(0);

PCF8574 ex1(0x20, &I2C);

uint16_t loco1Speed = 0;
uint16_t loco1SpeedPrevious = loco1Speed;
uint8_t loco1Address = 1;
bool loco1Dir = true;

uint16_t loco2Speed = 0;
uint16_t loco2SpeedPrevious = loco2Speed;
uint8_t loco2Address = 2;
bool loco2Dir = true;

void IRAM_ATTR onDirLoco1() {
  loco1Dir = !loco1Dir;
  loco1Speed = loco1Speed * -1;
}

void IRAM_ATTR onDirLoco2() {
  loco2Dir = !loco2Dir;
  loco2Speed = loco2Speed * -1;
}

void setup() {
  Serial.begin(9600);

  I2C.begin();

  if (!ex1.begin()){
    Serial.println("PCF8574 could not initialize");
  } if (!ex1.isConnected()) {
    Serial.println("PCF8574 not connected");
  }

  ESP32Can.setPins(CAN_TX, CAN_RX);
  if (!ESP32Can.begin(ESP32Can.convertSpeed(500))) {
    Serial.println("Starting CAN failed!");
  }

  u8g2.begin();
  u8g2.setFont(u8g2_font_logisoso32_tf);
  u8g2.setFontMode(0);

  attachInterrupt(DIR_LOCO_1_PIN, onDirLoco1, FALLING);
  attachInterrupt(DIR_LOCO_2_PIN, onDirLoco2, FALLING);
}

void loop() {
  loco1SpeedPrevious = loco1Speed;
  loco1Speed = analogRead(POTENTIOMETER_LOCO_1_PIN);
  loco1Speed = map(loco1Speed, 0, 1023, 0, 180);
  
  if (loco1Speed != loco1SpeedPrevious) {
    if (!loco1Dir) {
      loco1Speed = loco1Speed * -1;
    }
    sendLocoCmd(BASE_ADDRESS, loco1Address, loco1Speed, 0x00);
  }

  loco2SpeedPrevious = loco2Speed;
  loco2Speed = analogRead(POTENTIOMETER_LOCO_2_PIN);
  loco2Speed = map(loco2Speed, 0, 1023, 0, 180);

  if (loco2Speed != loco2SpeedPrevious) {
    if (!loco2Dir) {
      loco1Speed = loco2Speed * -1;
    }
    sendLocoCmd(BASE_ADDRESS, loco2Address, loco2Speed, 0x00);
  }

  drawLocoScreen(u8g2, loco1Speed, loco2Speed);
}

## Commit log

2025-07-23 cleaned up KiCAD files
    [Side.step, bom.csv, center.kicad_pcb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]
2025-07-24 updated README, split covers
    [BOM.csv, Control.kicad_pcb, bottom_cover.stl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]
